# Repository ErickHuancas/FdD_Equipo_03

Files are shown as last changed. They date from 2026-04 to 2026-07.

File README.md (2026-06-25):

# Equipo 03 - Fundamentos de Diseño
### Carrera de Ingeniería Informática, Industrial  y Ambiental
**Universidad Peruana Cayetano Heredia**

---

## 🌍 Descripción del Equipo  
Somos el **Equipo 03** del curso **Fundamentos de Diseño 2026-1**, conformado por estudiantes de la carrera de Ingeniería Informática, Industrial y Ambiental.  
Nuestro objetivo es aplicar la metodología de diseño para generar soluciones innovadoras con impacto social, tecnológico y ambiental.  

---

## 📌 Descripción

El equipo 03 desarrollará FreshTomato, un dispositivo tecnológico inteligente que clasifica tomates según su frescura y tiempo de vida útil utilizando ESP32-S3-WROOM-CAM, machine learning.

El objetivo principal de este proyecto es reducir perdidas en mercados, contribuyendo al cumplimiento de los ODS 2 (Hambre Cero), 11 (Ciudades Sostenibles), 12 (Producción y Consumo Responsable) y 13 (Acción por el Clima).

---

## ⚠️ Problemática en el Perú

En la costa peruana, especialmente en las principales zonas productoras como Ica, Lima y La Libertad, la cadena postcosecha del tomate enfrenta diversas dificultades documentadas por la industria y la academia:

1. **Pérdidas por maduración acelerada y reducción de vida útil**
   
   El tomate es una fruta climatérica que continúa su proceso de maduración después de la cosecha. Las temperaturas elevadas durante el almacenamiento y               transporte aceleran este proceso, reduciendo drásticamente su vida útil.

2. **Deterioro por almacenamiento inadecuado y exposición a condiciones variables**

   La exposición del tomate a temperaturas inadecuadas y a la luz acelera su maduración y favorece el desarrollo de daños fisiológicos:
      - Temperaturas superiores a 25°C: Aumentan la tasa respiratoria y aceleran la pérdida de calidad, provocando ablandamiento rápido y mayor susceptibilidada            daños mecánicos .
      - Temperaturas bajas (menores a 10°C): Pueden causar daño por frío (chilling injury), manifestándose como manchas superficiales, maduración irregular y               pérdida de sabor .
      - Humedad relativa baja (<85%): Acelera la pérdida de agua, provocando arrugamiento y pérdida de peso .

4. **Falta de herramientas accesibles para la evaluación de calidad**

   Actualmente, la evaluación de la calidad postcosecha del tomate se realiza mediante métodos subjetivos (presión manual u observación del color externo) o          destructivos (corte del fruto para verificar su estado interno). Los dispositivos comerciales existentes tienen costos elevados, lo que dificulta su               implementación en contextos rurales o de pequeña escala.

6. **Impacto ambiental por residuos**

    El desperdicio de Tomates genera un impacto negativo en el medio ambiente:
      - Los residuos orgánicos producen gases contaminantes durante su descomposición.
      - Se incrementa la cantidad de residuos sólidos en los mercados.
      - Se contribuye al cambio climático debido a la emisión de gases de efecto invernadero.

---

## 🍅 FreshTomato – Detector de Madurez y Factores Ambientales
### 💡 Propuesta de solución

Este proyecto tiene como objetivo desarrollar un sistema inteligente que detecte la frescura del tomate. Para ello, se emplean sensores de gases, temperatura y humedad, junto con visión artificial e inteligencia artificial.

La solución propuesta evalúa el estado interno del tomate sin dañarla, mediante el análisis de gases emitidos y características visuales externas.

A diferencia de los métodos tradicionales basados en inspección manual, esta propuesta permite una clasificación objetiva del producto. Además, estima el tiempo de vida útil restante, proporcionando información clave para la toma de decisiones.

### ¿Qué hace el dispositivo?

| Paso | Función |
|---|---|
| 1 | Captura una imagen del tomate con ESP32-S3-WROOM-CAM |
| 2 | Mide gases de descomposición con sensor MQ-135 |
| 3 | Registra temperatura y humedad con DHT22 |
| 4 | Clasifica el tomate como **Buen estado** o **mal estado** (Machine Learning con Edge Impulse) |
| 5 | Estima los *días de vida útil restantes* (1-12 días según temperatura y gas) |
| 6 | Muestra el resultado en una pagina web local|
| 7 | Envía una alerta al usuario con el estado y recomendación |

### 🎯 Población objetivo

Supermercados

Nos interesa trabajar en los siguientes **Objetivos de Desarrollo Sostenible (ODS):**
  
## 🌾 ODS 2: Hambre Cero

Este ODS busca la eliminación del hambre y garantizar que todas las personas tengan acceso a alimentos suficientes y nutritivos.

Nuestro grupo promueve el acceso equitativo a una alimentación sana, nutritiva y suficiente durante todo el año.

En el Perú, la inseguridad alimentaria es uno de los principales desafíos. Más de la mitad de la población se encuentra en riesgo, especialmente los niños y niñas, quienes no logran acceder a una alimentación adecuada.

Según la FAO (Organización de las Naciones Unidas para la Alimentación y la Agricultura), en 2024 el 51,7% de la población se encuentra en situación de inseguridad alimentaria moderada, lo que equivale a aproximadamente 17,6 millones de personas. Este dato posiciona al Perú como uno de los países con mayor prevalencia de inseguridad alimentaria en América del Sur.

La inseguridad alimentaria impacta directamente en el desarrollo infantil. Según el INEI (Instituto Nacional de Estadística e Informática), el 43,1% de los niños de 6 a 35 meses en Perú sufre anemia, lo que afecta su desarrollo físico y cognitivo.

Frente a esta problemática, existen iniciativas como World Vision, que promueve dietas balanceadas, estrategias multisectoriales y políticas públicas para combatir la anemia.

A nivel tecnológico, destacan:
- Plantix, desarrollada por PEAT GmbH, que utiliza inteligencia artificial para detectar enfermedades en cultivos.
- Crop Analytica, que emplea sistemas IoT para monitorear cultivos en tiempo real.
- Infarm, que implementa agricultura urbana con sensores en granjas verticales, reduciendo el uso de agua hasta en un 90–95%.

## 🏙️ ODS 11: Ciudades y Comunidades Sostenibles

Según el World Air Quality Report 2022, Perú se encuentra entre los países con mayor contaminación del aire en Latinoamérica.

Uno de los factores contribuyentes es la emisión de gases de efecto invernadero generados por la pérdida de alimentos. Cerca de 12,8 millones de toneladas de alimentos se desperdician al año, de los cuales más del 50% termina en botaderos.

Esto provoca la liberación de metano, un gas altamente contaminante, y aumenta la incidencia de enfermedades respiratorias en las zonas cercanas.

El ODS 11 busca el desarrollo de ciudades sostenibles, inclusivas y seguras, donde se garantice una buena calidad de vida sin comprometer el medio ambiente.

Ejemplos de soluciones:
- En California, el Laboratorio Nacional Lawrence Berkeley desarrolló sistemas para capturar metano en rellenos sanitarios y transformarlo en energía.
- Estudiantes de la Universidad de Alicante crearon un biosensor que detecta la frescura de alimentos, reduciendo el desperdicio.

## ♻️ ODS 12: Producción y Consumo Responsable

Este ODS promueve un modelo de consumo y producción sostenible, fundamental para las generaciones presentes y futuras.

Nuestro grupo promueve abordar la tercera meta que involucra este ODS que es poder reducir a la mitad el desperdicio de alimentos de alimentos per cápita en zonas rurales del Perú.

En el Perú:
- Se desperdician 12.8 millones de toneladas de alimentos al año (47.6% del total).
- Cada persona desperdicia en promedio 67.34 kg de alimentos al año.

Mientras tanto, más de 17 millones de peruanos viven en situación de inseguridad alimentaria.

Como señaló el Banco de Alimentos del Perú, una mejor gestión permitiría alimentar a millones de personas.

Ejemplos de soluciones:
- Too Good To Go, aplicación que permite comprar alimentos no vendidos a menor precio.
- Sistemas IoT para detectar la descomposición temprana de alimentos.

## 🌍 ODS 13: Acción por el Clima

Según el Ministerio del Ambiente, el Perú solo genera alrededor del 0.4% de los gases de efecto invernadero a nivel mundial. Sin embargo, es considerado el tercer país más vulnerable frente al cambio climático. Esta vulnerabilidad se refleja en distintos desastres naturales que afectan directamente a la población. Entre los años 2008 y 2019, aproximadamente 656,000 personas se vieron obligadas a abandonar sus hogares, perdiendo no solo sus viviendas, sino también sus medios de sustento.

Frente a esta situación, el ODS 13 tiene como propósito principal tomar medidas urgentes para combatir el cambio climático y reducir sus impactos. Nuestro proyecto aborda específicamente la meta 13.1, que busca fortalecer la resiliencia y la capacidad de adaptación a los riesgos climáticos, contribuyendo a reducir el desperdicio de alimentos y, con ello, las emisiones de metano generadas por residuos orgánicos en vertederos.

Algunos ejemplos de proyectos que contribuyen a este objetivo son:

- El Copernicus Programme, impulsado por la Unión Europea, que utiliza satélites y sensores para observar la Tierra en tiempo real y proporcionar datos abiertos sobre el medio ambiente.

- En El Salvador, se desarrolló un sistema IoT de bajo costo que permite monitorear la calidad del aire y acceder a información sobre la contaminación desde cualquier dispositivo con conexión a internet.

---

## 📚 Fuentes

Alicante, N. U. de. (2024). NANOBIOPOL (Grupo de investigación de Análisis de Polímeros y Nanomateriales)

CH4 Pathways. (s/f). Captura del gas de rellenos sanitarios

Coca Pimentel, V. (2023, septiembre 23). Contaminación del aire en Perú: El 58% proviene del parque automotor.

Comex.Perú. (2022, febrero 11). Solo aprovechamos el 1% de residuos orgánicos e inorgánicos que generamos.

Dirección de Estudios Económicos & Dirección General de Políticas Agrarias. (2022). Pérdidas y desperdicios de alimentos en el Perú. 

MINAM. (2024, mayo 16). Más de 148 500 toneladas de residuos sólidos municipales son valorizados en el país.

Visión Mundial Perú. (2024, 10 de diciembre). Inseguridad alimentaria en Perú.

AgroPerú Informa. (2025, septiembre 23). Pérdida y desperdicio de alimentos: un reto que exige innovación y colaboración.

La República. (2021, marzo 20). En el Perú, la mitad de los alimentos termina en la basura, según estudio.

IoT M2M Council. (2021, marzo 17). Infarm launches new vertical farming centres. Hasib, A., & Sarkar Akib, A. S. M. A. (2026).

An IoT-based smart plant monitoring and irrigation system with real-time environmental sensing, automated alerts, and cloud analytics. arXiv.

---

## 📸 Fotografía del Equipo  
<p align="center">
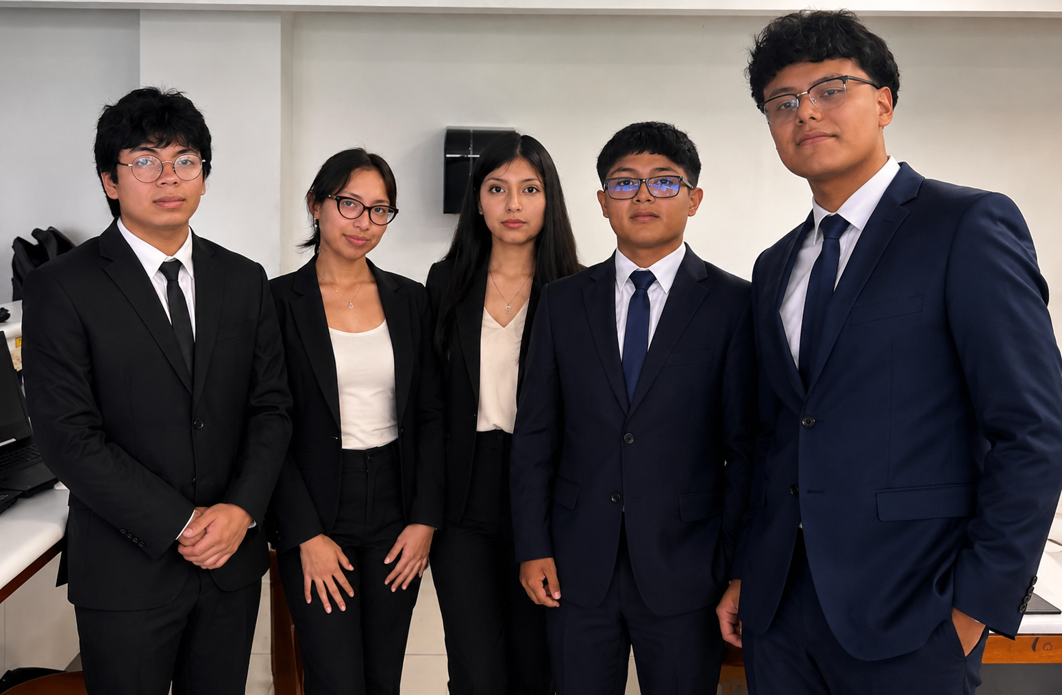
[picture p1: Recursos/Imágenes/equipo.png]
imagen_alumnos_IA

  <em>Figura 1. Fotografía del equipo 03</em>
</p>

---

## 👥 Integrantes del Equipo  

| Foto | Nombre | Rol | Intereses |
|---|---|-----|---|
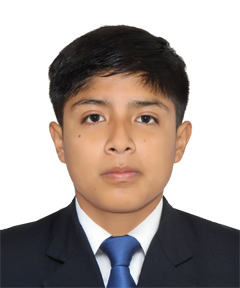
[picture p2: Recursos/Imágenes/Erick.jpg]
|  | **Erick Huancas Bereche** erick.huancas@upch.pe| Líder del equipo | Innovación social, sostenibilidad, liderazgo, emprendedor |
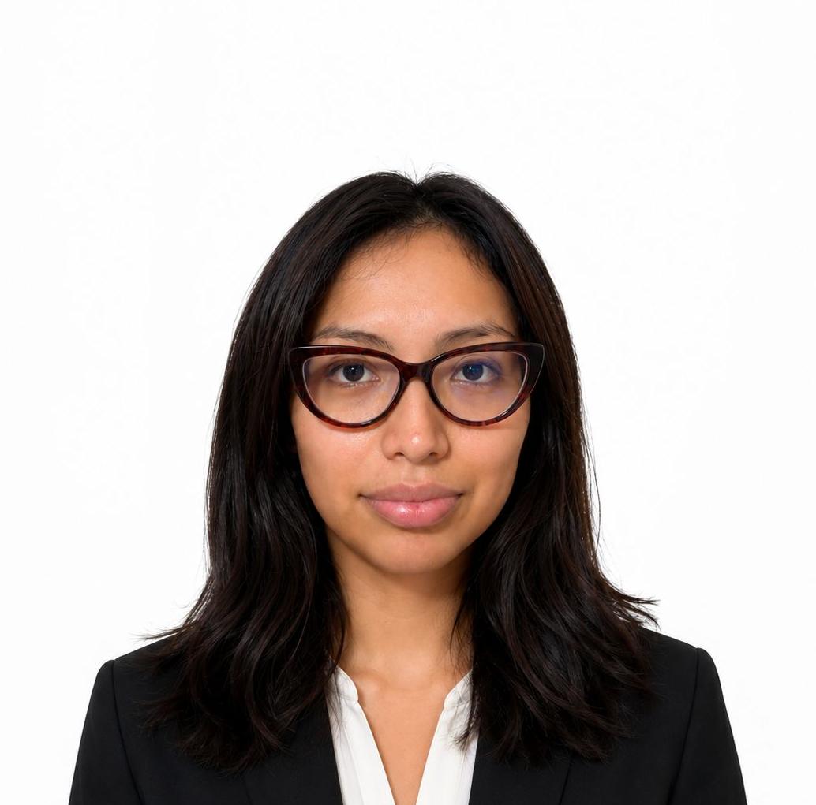
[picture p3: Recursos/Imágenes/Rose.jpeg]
|  | **Rose Suazo Davila** rose.suazo@upch.pe | Responsable de investigación | Gestión ambiental, desarrollo comunitario, investigación cientifica |
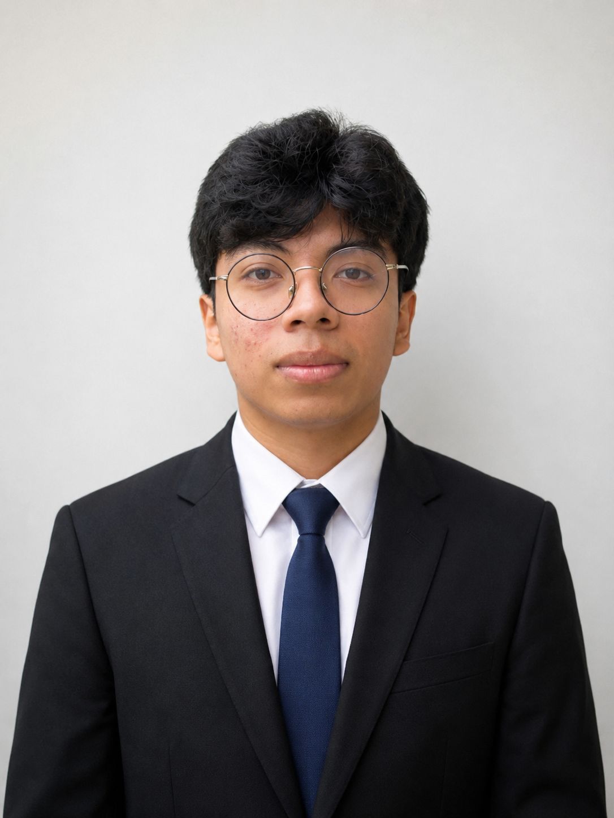
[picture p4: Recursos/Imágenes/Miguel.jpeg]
|  | **Miguel Ruiz Trelles** miguel.ruiz@upch.pe | Diseñador/a | Diseño de prototipos, creatividad aplicada, impacto ambiental |
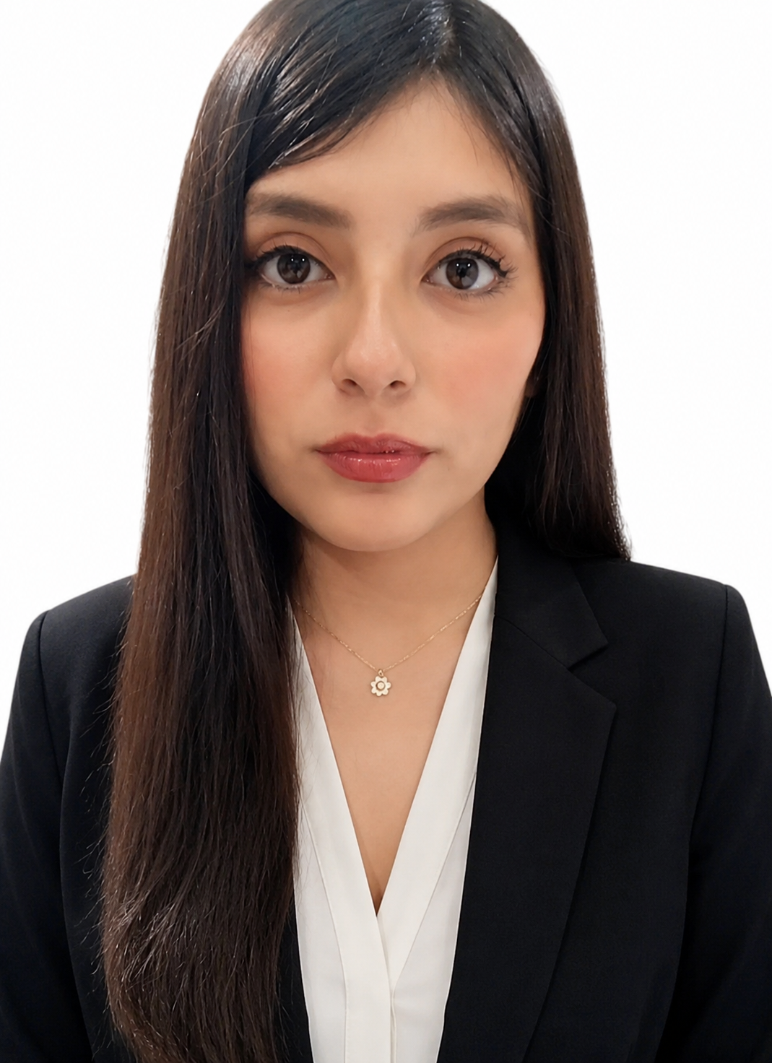
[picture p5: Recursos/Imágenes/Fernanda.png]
|  | **Paloma Velasquez Saforas** paloma.velasquez@upch.pe | Encargado/a de documentación | Comunicación científica, redacción técnica, investigación |
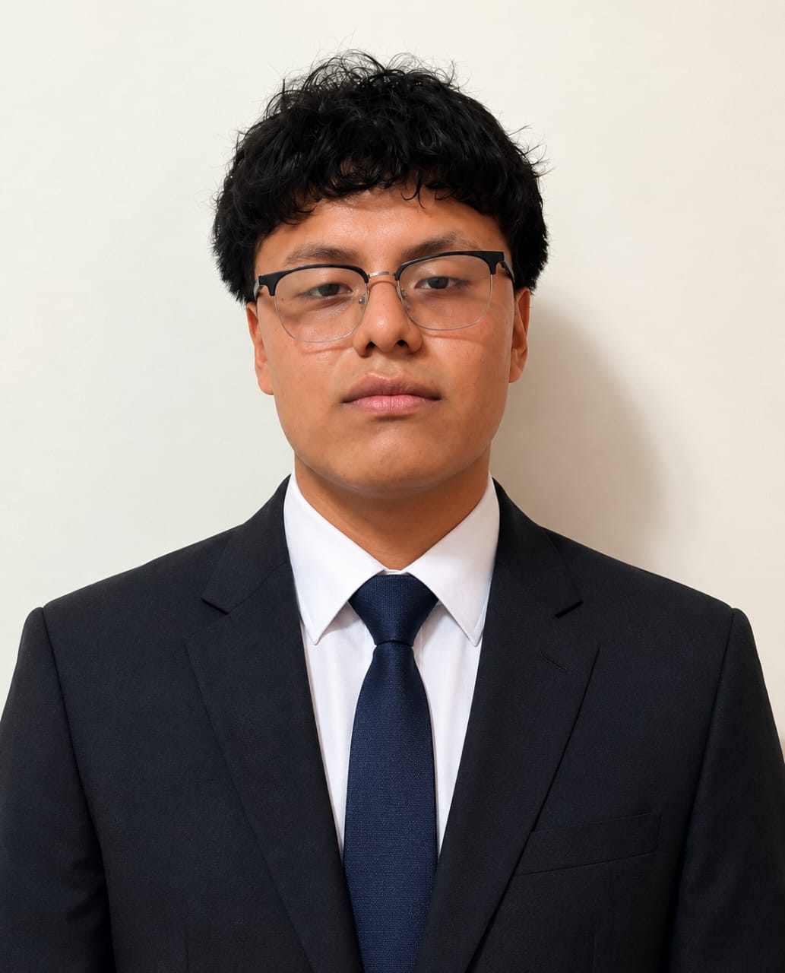
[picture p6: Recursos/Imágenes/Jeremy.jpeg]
|  | **Jeremy Mendez Ponce De Leon** jeremy.mendez@upch.pe | Programador/a - Modelador/a | Programación, análisis de datos, simulación |

---

## 📌 Resumen Final  
Este README resume quiénes somos, qué nos motiva y en qué ODS queremos enfocar nuestro trabajo durante el curso.

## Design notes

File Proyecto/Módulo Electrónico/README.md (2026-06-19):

# Reporte de Evolución y Mejoras del Diseño Esquemático
## Proyecto: Sistema de Monitoreo Agrícola "FreshTomato"

Este documento presenta de forma técnica y detallada la evolución del diseño electrónico del proyecto **FreshTomato**, detallando el histórico de las cuatro (4) versiones del esquemático hasta consolidar una solución final estable, eficiente y protegida contra ruidos eléctricos y conflictos de hardware.

---

## 📊 Cuadro Comparativo de Versiones

| Parámetro / Componente | Versión 1.0 (Inicial) | Versión 2.0 (Transición) | Versión 3.0 (Corrección) | Versión Final (Estabilizada) |
| :--- | :--- | :--- | :--- | :--- |
| **Microcontroladores** | 2 placas (ESP32 DevKit + ESP32-CAM) | 1 placa (ESP32-S3-WROOM-1 CAM) | 1 placa (ESP32-S3-WROOM-1 CAM) | 1 placa (ESP32-S3-WROOM-1 CAM) |
| **Actuador (Servo)** | No incluido | MG996R (Conectado a salida Stepdown) | MG996R (Conectado a salida Stepdown) | MG996R (Línea de 7.2V directa + Switch) |
| **Alimentación General** | Fuentes separadas no reguladas | Stepdown de 7V a 5V general | Stepdown de 7V a 5V general | **Fuentes Independientes (USB + Cargador 5V/2A + 7.2V)** |
| **Manejo de Pines (CAM)** | Sin restricciones (No integrados) | **Conflicto Crítico** (Pines de la cámara ocupados) | **Corregido** (Reasignación a pines libres) | **Optimizado** con protección en la señal del Servo |
| **Filtrado MQ135** | Sin capacitor de desacoplo | Sin capacitor de desacoplo | Sin capacitor de desacoplo | **Capacitor Electrolítico de 100 µF** |
| **Protección Lógica** | No incluida | No incluida | No incluida | **Divisores resistivos** para entradas analógicas/lógicas |

---

## 🔍 Análisis Detallado de la Evolución del Circuito

### 🔴 Versión 1.0: Arquitectura Duplicada (Inicial)
La primera aproximación del proyecto dependía de dos procesadores independientes para segmentar las tareas:
* **Componentes:** Un ESP32 clásico (para la lectura de sensores) y un ESP32-CAM (únicamente dedicado al procesamiento de imágenes).
* **Limitaciones:** El circuito no incluía servomotor. Carecía de filtros de desacoplo en la línea del sensor de gas MQ135, lo que provocaba lecturas altamente inestables debido al ruido térmico del calentador interno del sensor. La comunicación entre ambos microcontroladores complejizaba innecesariamente el código y aumentaba el consumo energético.

### 🟠 Versión 2.0: Unificación de Hardware y Errores de Conmutación
Con el fin de optimizar costos y espacio, se migró a un único procesador potente y se introdujo fuerza mecánica:
* **Mejoras:** Se reemplazaron las dos placas por un único **ESP32-S3-WROOM-1 CAM**. Se integró el servomotor de alto torque (MG996R) y un regulador conmutado *Stepdown* para reducir el voltaje de las baterías de 7V a 5V.
* **Errores Críticos Identificados:** 1.  **Conflicto de Pines CSI:** Se asignaron las líneas de control del servo (`GPIO6`), el DHT22 (`GPIO4`) y el MQ135 (`GPIO1`) a pines que la cámara utiliza internamente para el bus de datos y bus de control SCCB. Esto corruptora las capturas de imagen y reseteaba el procesador.
    2.  **Cortes de Tierra:** El interruptor general se ubicó interrumpiendo la línea de masa (`GND`), dejando el circuito flotante.

### 🟡 Versión 3.0: Corrección de Matriz de Pines
Esta versión se enfocó exclusivamente en resolver la interacción de hardware a nivel de software y distribución de pistas:
* **Mejoras:** Se realizó un mapeo profundo de la hoja de datos del ESP32-S3 CAM. Se liberaron por completo los pines internos de la cámara y se reubicaron las señales del Servo, DHT22 y MQ135 hacia GPIOs libres (como `GPIO8`, `GPIO9`, etc.). El interruptor fue movido a la línea positiva antes de la regulación.

### 🟢 Versión Final: Independencia de Potencia y Estabilidad Señal-Ruido
La versión definitiva del esquemático soluciona los problemas de caídas de tensión y picos de corriente aislando los caminos eléctricos por su naturaleza de consumo:

1.  **Aislamiento de la Etapa de Potencia del Servomotor:** * El servomotor MG996R demanda corrientes pico elevadas al romper la inercia. Se conectó de forma directa a la línea del portabaterías de **7.2V** (aprovechando su rango máximo de operación).
    * Se le integró un **Switch dedicado** en el positivo para cortar su energía cuando no esté operando, erradicando el consumo parásito y previniendo sobrecalentamientos.
2.  **Filtrado Eléctrico para el Sensor MQ135:**
    * El MQ135 posee una resistencia calefactora que genera picos cíclicos de demanda. Para mitigar las fluctuaciones en las lecturas analógicas, se energizó mediante un **cargador externo dedicado de 5V a 2 Amperios**.
    * Se colocó un **capacitor electrolítico de 100 µF** en paralelo entre `VCC` y `GND` del sensor, absorbiendo los rizos de corriente y estabilizando los voltajes de lectura.
3.  **Alimentación Lógica Limpia:**
    * El **ESP32-S3-WROOM-1 CAM** y el sensor **DHT22** se alimentan mediante el bus USB conectado a una laptop, garantizando una fuente conmutada limpia, ideal para el procesamiento de la IA y el envío de datos.
4.  **Adaptación de Niveles con Divisores Resistivos:**
    * Se incluyeron **divisores resistivos** calculados en las salidas de las señales analógicas/lógicas para adecuar los voltajes al rango seguro de tolerancia del ADC del ESP32-S3 ($0	ext{ V} - 3.3	ext{ V}$), protegiendo las compuertas lógicas contra degradación por sobrevoltaje.

---

## 🎯 Conclusión del Proceso de Ingeniería
El diseño final abandonó la regulación única con *Stepdown* general debido a que los tirones del servomotor y el ruido del calefactor del MQ135 degradaban la estabilidad del ESP32-S3. La arquitectura final de **Fuentes Distribuidas** (Batería 7.2V para motor + Cargador 5V/2A para sensor de gas + USB para lógica) asegura un funcionamiento continuo de 24/7 sin reinicios imprevistos, lecturas analógicas confiables y una captura de video nítida.

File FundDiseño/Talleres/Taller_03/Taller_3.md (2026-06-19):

# CAPÍTULO I: INTRODUCCIÓN

## Situación Problemática

---

## Contexto General
El desperdicio de alimentos es una problemática significativa y persistente en los sistemas alimentarios de hoy en día.  En el Perú, existen estudios sobre pérdidas en la agricultura que señalan niveles altos de desperdicio orgánico, especialmente durante la poscosecha; donde las frutas y verduras son las más afectadas por su rápida descomposición y vida útil corta.

Entre los productos más afectados destaca el tomate (Solanum lycopersicum L.), una de las hortalizas de mayor consumo en la dieta diaria peruana. Debido a su alta perecibilidad y elevado contenido de agua, este cultivo presenta una rápida pérdida de calidad durante las etapas de almacenamiento y comercialización, lo que genera importantes pérdidas antes de llegar al consumidor final. Diversos estudios sobre manejo poscosecha señalan que el deterioro del tomate está estrechamente relacionado con condiciones inadecuadas de manipulación, temperatura y tiempo de almacenamiento, factores que incrementan significativamente las pérdidas dentro de la cadena de comercialización (1,2)

A nivel nacional, los informes señalan a la podredumbre como causa principal con un 27% de las pérdidas. Por otro lado, el verdeamiento y la pérdida de agua con un 22% y 14% respectivamente. Asimismo, los golpes mecánicos y la mala clasificación de los tomates cada uno con un 11% de las pérdidas. Por lo tanto, la monitorización de las condiciones ambientales durante la distribución y venta es crítica para mitigar la degradación acelerada del tomate (2).

En este contexto, el desperdicio de tomate en los mercados representa una problemática persistente dentro de la cadena de abastecimiento alimentario, asociada principalmente a deficiencias en el manejo poscosecha, almacenamiento y comercialización, generando impactos económicos para comerciantes y productores, así como una mayor contribución en los niveles de desperdicios de alimentos generados. 

## Contexto en el sector comercial
En el sector retail, las pérdidas de los alimentos perecibles, como el tomate, tiene un impacto significativo en la cadena de suministro y durante la gestión de inventario; proceso que busca conservar la calidad del producto hasta la obtención final del cliente mediante un elevado nivel de gestión en el planeamiento de su logística. Por lo tanto, es necesario mencionar que la vida útil del tomate no está en función únicamente de factores biológicos, sino de las condiciones de almacenamiento en la que se encuentra al establecerse en las cadenas de retail alimentario (3). 

Este comercio minorista de alimentos cuenta con una amplia gama de estrategias para minimizar el desperdicio y evitar que sus productos caduquen antes de ser comprados. Sin embargo, muchos de los mecanismos empleados no permiten un mayor control sobre los alimentos. Dentro de las políticas de inventarios, a menudo se utilizan los sistemas de seguimiento de inventario First-In-First-Out (FIFO), que refiere a la venta de los productos que se adquieren primero, quedando en el inventario los productos que fueron adquiridos recientemente (4). No obstante, un estudio no experimental mediante encuestas en una de las grandes cadenas de retail, evidenció que el nivel de uso y efectividad del sistema FIFO es baja, esto confirma que la gestión de inventarios basada únicamente en un sistema dinámico de almacenaje es insuficiente para productos de alta tasa respiratoria como el tomate. (4) Este mecanismo ignora la variabilidad biológica de cada lote de tomate, es decir que la jaba adquirida recientemente presenta índices de emisión de etileno superiores a los de una jaba antigua.

 Por consiguiente, para apoyar de manera eficiente la cadena de suministro, no solo basta con el uso de una cadena de frío con condiciones de temperaturas óptimas, sino del uso de tecnologías que sean capaces de monitorear el estado fisiológico del tomate; logrando detectar anomalías químicas en lotes específicos que la temperatura no logra revelar y asegurando una toma de decisiones basada en el estado real de degradación del producto. 

---

# Propuesta de solución
En el Perú, especialmente en regiones costeras como Ica, Lima y La Libertad, los supermercados enfrentan pérdidas significativas de tomate debido a condiciones inadecuadas de almacenamiento y exhibición. Factores como temperaturas no controladas, variaciones de humedad y largos tiempos de exposición aceleran el deterioro del producto, reduciendo su vida útil en los puntos de venta. Asimismo, la evaluación de la calidad del tomate se realiza principalmente mediante inspecciones visuales, las cuales son subjetivas y dependen del criterio del personal, lo que limita la detección temprana del deterioro; además, muchos establecimientos no cuentan con sistemas tecnológicos que permitan un monitoreo continuo, objetivo y en tiempo real.

Según un estudio, demostró que la calidad del tomate, evaluada mediante atributos como firmeza, color e índice general de calidad, disminuye rápidamente bajo condiciones ambientales, afectando directamente su aceptación por parte del consumidor. En particular, se ha evidenciado que solo una pequeña proporción de tomates en estado deteriorado mantiene aceptación comercial, lo que resalta la necesidad de implementar sistemas de monitoreo temprano y preciso que permitan evitar pérdidas y rechazos en el punto de venta.(5)

Enfrentados a este problema, es necesario encontrar soluciones tecnológicas que nos permitan monitorear la situación de manera objetiva. Para resolver esto, se propone crear un sistema inteligente llamado FreshTomate. Este sistema utiliza sensores que miden los gases, la temperatura y la humedad, además de técnicas de visión artificial y de inteligencia artificial. Todo esto nos permite monitorear el estado del tomate en tiempo real.

El sistema se aplicará en un momento crítico de la cadena de suministro, específicamente durante la etapa de recepción de mercancía, es decir, antes de que los tomates entren a la cadena de frío. En este lugar, el aparato operará como un filtro de calidad, posibilitando la revisión del estado del producto previo a su almacenamiento en cámaras frigoríficas. Así, se previene que entren productos en malas condiciones que pudieran perjudicar la calidad del lote restante.
Para su funcionamiento, el sistema utiliza un microcontrolador llamado ESP32-CAM. Este microcontrolador permite procesar datos y capturar imágenes del tomate para analizarlo.(6,7) También se utiliza un sensor de gases llamado MQ-135. Este sensor detecta gases como amoníaco y dióxido de carbono que se producen cuando el tomate se descompone.(8) Además, se utiliza un sensor llamado DHT22 para medir la temperatura y la humedad. Estas variables son importantes porque influyen en la maduración del tomate.(9)

Los datos que se recopilan de estos sensores se procesan con una herramienta de aprendizaje automático desarrollada con Edge Impulse. Esta herramienta puede ser entrenada para clasificar el estado del tomate en dos categorías: apto para el consumo y no apto para el consumo. Esta clasificación es rápida y no daña el tomate. Es mejor que los métodos tradicionales.

Además, el sistema dispondrá de una fuente de alimentación con baterías, lo que posibilitará su funcionamiento independiente y hará más fácil su instalación en varios lugares dentro del área de recepción sin la necesidad de tener una conexión eléctrica fija.

En resumen, el sistema permite vigilar las condiciones ambientales y el estado del tomate. Esto nos da alertas antes de que haya problemas y nos ayuda a tomar decisiones. Con tecnologías modernas y fáciles de usar, podemos mejorar la calidad, reducir el desperdicio de comida y gestionar mejor los supermercados. Además, esto se ajusta a la norma ISO 22000, que busca asegurar que los alimentos sean seguros y controlar los riesgos en toda la cadena de suministro del tomate.

---

# Objetivos

## Objetivo general

Diseñar e implementar un sistema ciberfísico inteligente denominado FreshTomate, basado en el uso del microcontrolador ESP32-CAM, sensores ambientales y técnicas de aprendizaje automático, que permita evaluar y monitorear en tiempo real la vida útil del tomate (Solanum lycopersicum L.)

## Objetivos específicos

- Realizar un estudio del estado del arte que permita identificar las tecnologías aplicadas en la detección de la frescura de alimentos, incluyendo sensores de gases, visión artificial e inteligencia artificial.
- Desarrollar el sistema físico mediante la selección e integración de componentes electrónicos, incluyendo sensores de gas, temperatura y humedad, así como el módulo ESP32-CAM para la captura de imágenes.
- Diseñar e implementar un modelo de inteligencia artificial que permita clasificar la frescura del tomate y estimar su vida útil, utilizando técnicas de aprendizaje automático.
- Realizar pruebas de funcionamiento para validar la precisión en la detección de la frescura y el procesamiento de datos provenientes de los sensores y del sistema de visión artificial.
- Evaluar el desempeño del sistema mediante pruebas experimentales, comparando los resultados obtenidos con métodos tradicionales de inspección manual en la detección temprana del deterioro del tomate, en condiciones similares al entorno comercial.

---

# CAPÍTULO II: ESTADO DE ARTE
## Métodos tecnológicos para la detección de frescura y descomposición en frutas y vegetales
De acuerdo con la literatura revisada (10,11), existen diferentes métodos tecnológicos para el monitoreo y detección de frescura en alimentos, que mediante el uso de microcontroladores, sensores de gas y algoritmos de inteligencia artificial (Edge Impulse) permiten clasificar el estado de maduración o descomposición de frutas y vegetales. 

Asimismo, investigaciones recientes evidencian el uso de tecnologías IoT con dispositivos como ESP32, combinados con sensores y plataformas en la nube, para el monitoreo en tiempo real de la calidad de los alimentos durante su almacenamiento y transporte (11).

Además de los artículos académicos revisados, existen implementaciones prácticas documentadas en plataformas de código abierto. Markel (2025) desarrolló un sistema de detección de madurez aplicable a frutas utilizando Machine Learning, logrando una precisión del 100% en sus pruebas con tomates, demostrando la viabilidad técnica del enfoque.

---

## Clasificación de tomates con ESP32-CAM y Edge Impulse

Consiste en el uso de un microcontrolador ESP32-CAM con cámara integrada (OV2640, 2 megapíxeles) que captura imágenes de tomates en tiempo real. Estas imágenes son procesadas mediante un modelo de red neuronal convolucional profunda ResNet entrenado en la plataforma Edge Impulse. El sistema clasifica los tomates en diferentes categorías según su tamaño, madurez y calidad. Los datos se transmiten a una plataforma IoT en la nube, permitiendo a los agricultores acceder a la información de forma remota para tomar decisiones sobre la cosecha y reducción de desperdicios.(10)

Entre sus principales ventajas destaca el uso de hardware de bajo costo, como el ESP32-CAM, así como el empleo de la plataforma Edge Impulse, que es gratuita. Además, el sistema presenta un gran potencial para reducir el desperdicio de alimentos a lo largo de la cadena de suministro.(10)

Sin embargo, también presenta algunas limitaciones. Una de ellas es la limitada integración de sensores, ya que los propios autores señalan que, como trabajo futuro, será necesario incorporar sensores ambientales adicionales (como temperatura, humedad y gases). Asimismo, el sistema depende de la conexión a internet, por lo que, ante una falla en la conectividad, deja de funcionar correctamente.(10)

## Desarrollo de una plataforma basada en IoT y aprendizaje automático para la evaluación de la madurez de la fruta y la detección de su deterioro.

Se trata de la creación de un sistema que utiliza Internet de las Cosas (IoT) y aprendizaje automático con el fin de analizar la maduración y encontrar frutas en mal estado, haciendo uso para ello de un microcontrolador ESP32. El sistema cuenta con sensores como el SHT40 para determinar la humedad y la temperatura, y el SGP30 para identificar gases como compuestos orgánicos volátiles (TVOC), CO₂ equivalente, hidrógeno y etanol. Estos son indicadores fundamentales del proceso de descomposición y maduración. Los datos se recopilan en tiempo real y se transfieren a la plataforma ThingSpeak, que está basada en la nube. En esta plataforma, los datos son almacenados, procesados y visualizados para crear un conjunto de datos que facilita el entrenamiento de modelos de machine learning con el objetivo de prever el estado de la fruta desde su fase inicial hasta su deterioro.(11)

Entre sus principales ventajas destaca la integración de sensores avanzados que pueden medir tanto las variables ambientales como los gases específicos relacionados con el proceso de maduración es uno de sus principales beneficios, lo cual facilita un análisis más exacto e imparcial. Además, el empleo del ESP32 hace posible la transmisión de datos sin cables y el seguimiento remoto en tiempo real a través de plataformas IoT como ThingSpeak. Asimismo, la creación de conjuntos de datos a través del tiempo mejora la exactitud de los modelos predictivos y favorece el avance de sistemas inteligentes utilizados en agricultura y conservación alimentaria.(11)

Sin embargo, el sistema también presenta algunas limitaciones. Una de ellas es la necesidad de recolectar grandes volúmenes de datos durante varios días para lograr modelos de aprendizaje automático confiables. Asimismo, el rendimiento de los sensores de gases puede verse afectado por condiciones ambientales externas y por su propia degradación con el tiempo, lo que exige calibraciones y mantenimiento periódico. También existe la posibilidad de obtener mediciones alteradas debido a interferencias del entorno, lo que podría generar errores en la clasificación. Por otro lado, su implementación requiere cierto nivel de conocimiento técnico y una inversión inicial. Finalmente, el sistema depende de la conectividad a internet para el envío y visualización de datos en la nube, lo que puede representar una limitación en entornos con baja cobertura.(11)

## BIBLIOGRAFÍA
- Córdova Peña, Moisés Teodoro, Pinasco Alegre, Renzo Giovanni, Pizarro Chirinos, Giannina Josefina, Quiñones Jara, Teófilo Marcelo, Córdova Peña. laneamiento Estratégico del Tomate en el Perú [Tesis de maestría]. [Surco, Perú]: Pontificia Universidad Católica del Perú; 2016. 
- María Yovani Irigoín Lara. Vida útil de tomate (Solanum lycopersicum L. var. Sheila Victory F1) cosechado en dos estados de madurez y almacenados en diferentes tiempos y temperaturas [Tesis para optar el título profesional de Ingeniero en Industrias Alimentarias]. [Cajamarca, Perú]: Universidad Nacional de Cajamarca; 2024. 
- Salas BDM, David O, Díaz P, Joel D, Lozano V, Vanessa C. GESTIÓN DE   INVENTARIOS PERECIBLES ADAPTADA PARA LAS DECISIONES SOBRE EL SUMINISTRO: ESTUDIO DE CASO DEL PROCESO DE PLANIFICACIÓN DEL ABASTECIMIENTO DE YOGURES EN HIPERMERCADOS TOTTUS.
- Espinoza DRL. Gestión de Inventarios y la merma de productos perecederos en hipermercados Tottus. 2023;115.
- M R, Voola P. Developing an IoT and ML-driven platform for fruit ripeness evaluation and spoilage detection: A case study on bananas. E-Prime - Adv Electr Eng Electron Energy. el 1 de marzo de 2025;11:100896. doi:10.1016/j.prime.2025.100896
- Aftab RA, Ahmad F, Monish M, Zaidi S. Postharvest quality assessment of tomato during storage: An experimental and ML fusion. J Stored Prod Res. 1 de mayo de 2025;112:102643. doi:10.1016/j.jspr.2025.102643
- Kulkarni SM, Umadi S, R m A, Airani SS, Raikar MM. Grading and Classification of Tomatoes Using ESP32-CAM and Impulse Cloud based IoT Platform for Sustainability. Procedia Comput Sci. 1 de enero de 2025;Seventh International Conference on Recent Trends in Image Processing and Pattern Recognition (RTIP2R-2024)260:938-46. doi:10.1016/j.procs.2025.03.277 
- Santos S. Guía de asignación de pines del ESP32-CAM AI-Thinker: Explicación del uso de los GPIO | Tutoriales de Random Nerd [Internet]. 10 de marzo de 2020 [citado 2 de abril de 2026]. Disponible en: https://randomnerdtutorials.com/esp32-cam-ai-thinker-pinout/
- Tangirbergen A, Tleubekova A, Yergaliuly G, Kurmanbayeva A, Soltabayev B, Soltabayeva A. Real-time detection of potato spoilage by gas sensor array coupled with microbiological analysis. LWT. 1 de enero de 2026;239:118926. doi:10.1016/j.lwt.2025.118926
- K.VENKATARAMANAN, D.PRASANTH, V.SHEEBA, R.KUMARESAN. SMART FOOD SPOILAGE PREDICTION AND ALERT SYSTEM. Int J Nexus Knowl Multidiscip J Online ISSN 3108-0529. 3 de julio de 2025;1(1):62-9.
- M R, Voola P. Developing an IoT and ML-driven platform for fruit ripeness evaluation and spoilage detection: A case study on bananas. E-Prime - Adv Electr Eng Electron Energy. 1 de marzo de 2025;11:100896. doi:10.1016/j.prime.2025.100896

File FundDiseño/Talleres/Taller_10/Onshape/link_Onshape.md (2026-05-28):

https://cad.onshape.com/documents/e68281a320b0caf378c65360/w/9e2ba7427c716612348f81b5/e/db65db4494cec690573642d6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

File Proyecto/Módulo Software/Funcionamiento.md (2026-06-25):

# Módulo de Software

## Descripción General

El módulo de software constituye el núcleo del sistema, permitiendo la comunicación entre el sistema embebido ESP32-S3-WROOM-CAM, el servidor Flask, el modelo de Machine Learning y la interfaz de usuario. Su función principal es procesar las imágenes y datos ambientales adquiridos, estimar la vida útil del tomate y almacenar los resultados obtenidos.

---

# Componentes del Sistema

## Dashboard Web

La interfaz web permite:

- Iniciar una nueva evaluación.
- Visualizar el progreso del proceso.
- Mostrar los resultados de clasificación.
- Consultar el historial de análisis almacenados.

---

## Servidor Flask

El servidor Flask actúa como núcleo del sistema y es responsable de:

- Recibir las solicitudes provenientes del Dashboard.
- Comunicarse con el ESP32-S3-WROOM-CAM mediante HTTP.
- Procesar las imágenes capturadas.
- Ejecutar el modelo de Machine Learning.
- Calcular la vida útil del tomate.
- Almacenar los resultados en una base de datos SQLite.

---

## Sistema Embebido ESP32-CAM

El ESP32-S3-WROOM-CAM se encarga de:

1. Consultar continuamente el estado del servidor.
2. Ejecutar un ciclo de adquisición cuando recibe una orden de inicio.
3. Posicionar el servomotor en tres ángulos diferentes (0°, 90° y 180°).
4. Leer la temperatura mediante el sensor DHT22.
5. Leer la concentración de gases mediante el sensor MQ135.
6. Capturar una imagen de cada cara del tomate.
7. Enviar la información al servidor Flask.

---

## Modelo de Machine Learning

Se emplea una red neuronal convolucional basada en MobileNetV2 entrenada para clasificar tomates en dos categorías:

- Tomate sano.
- Tomate malogrado.

El modelo recibe imágenes RGB de tamaño 224×224 píxeles y genera una probabilidad mediante una función de activación sigmoide.

La clasificación se realiza mediante:

- Probabilidad ≥ 0.5 → Tomate sano.
- Probabilidad < 0.5 → Tomate malogrado.

---

## Estimación de Vida Útil

La vida útil restante se estima considerando tres factores principales:

### Temperatura

Se emplea el modelo Q10, donde un incremento de 10°C aproximadamente duplica la velocidad de deterioro.

### Concentración de gases

El sensor MQ135 proporciona una medida relativa del deterioro mediante la detección de compuestos volátiles emitidos durante el proceso de maduración y descomposición.

### Confianza del modelo

La confianza obtenida por MobileNetV2 permite ajustar la estimación de forma conservadora cuando existen predicciones poco seguras.

---

# Flujo General de Funcionamiento

1. El usuario presiona el botón **"Iniciar Evaluación"** desde el Dashboard.
2. El Dashboard envía una solicitud POST al servidor Flask.
3. Flask genera un identificador único de sesión para asociar las tres caras del tomate.
4. El ESP32-S3-WROOM-CAM consulta periódicamente el estado del servidor mediante GET `/estado`.
5. Al recibir la orden de inicio, comienza el ciclo de adquisición.
6. El servomotor posiciona el tomate en tres orientaciones diferentes (0°, 90° y 180°).
7. En cada posición se registran:

   - Temperatura (DHT22).
   - Concentración de gases (MQ135).
   - Imagen capturada por la cámara.

8. Cada etapa es enviada al servidor Flask mediante HTTP POST.
9. Al completar las tres etapas, el ESP32-S3-WROOM-CAM notifica la finalización del proceso.
10. Flask procesa las imágenes utilizando MobileNetV2.
11. Se calcula la temperatura promedio y la concentración promedio de gases.
12. Se estima la vida útil restante del tomate.
13. Los resultados se almacenan en SQLite.
14. El Dashboard muestra la clasificación y el historial de evaluaciones.

---

# Comunicación Entre Componentes

## Dashboard → Flask

```text
POST /iniciar
```

Solicita el inicio de una nueva evaluación.

---

## ESP32 → Flask

Consulta periódicamente:

```text
GET /estado
```

para verificar si debe iniciar una nueva adquisición.

---

## Envío de las Etapas

Para cada etapa, el ESP32-S3-WROOM-CAM envía:

### Cabeceras HTTP

```text
X-Session
X-Etapa
X-Temp
X-MQ135
```

### Cuerpo del mensaje (Body)

```text
Imagen JPEG capturada por la ESP32-S3-WROOM-CAM
```

mediante:

```text
POST /etapa
```

---

## Finalización del Proceso

Una vez completadas las tres etapas:

```text
POST /finalizar
```

El servidor Flask procesa toda la información adquirida.

---

# Base de Datos SQLite

La información almacenada incluye:

- Fecha y hora del análisis.
- Identificador de sesión.
- Resultado de clasificación.
- Nivel de confianza.
- Temperatura promedio.
- Concentración promedio de gases.
- Vida útil estimada.
- Rutas de almacenamiento de las imágenes.

---

# Tecnologías Utilizadas

| Componente | Tecnología |
|---|---|
| Sistema Embebido | ESP32-S3-WROOM-CAM |
| Servidor | Flask |
| Lenguaje | Python |
| Machine Learning | TensorFlow + MobileNetV2 |
| Procesamiento de Imágenes | Pillow + NumPy |
| Base de Datos | SQLite |
| Comunicación | HTTP |
| Interfaz Gráfica | HTML + CSS + JavaScript |
| Sensor de Temperatura | DHT22 |
| Sensor de Gases | MQ135 |
| Actuador | Servo MG996R |

---

# Conclusión

El módulo de software integra la adquisición de datos, el procesamiento mediante inteligencia artificial, la estimación de vida útil y el almacenamiento de información, permitiendo la clasificación automática del estado del tomate y proporcionando una aproximación de su tiempo de conservación restante.

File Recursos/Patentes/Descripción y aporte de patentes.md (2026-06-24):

# Cuadros Técnicos de las Patentes del Proyecto

Este documento presenta los cuadros técnicos de las patentes identificadas para el proyecto.

---

## Cuadro Técnico de la Patente 01

| Componente | Detalle |
| :--- | :--- |
| **Título** | Método y dispositivo para detectar la madurez de frutas y verduras |
| **Título Original** | Method and device for detecting maturity of fruits and vegetables |
| **Código** | `CN114659918A` |
| **Enlace de consulta** | [Espacenet - CN114659918A](https://worldwide.espacenet.com/patent/search/family/082037969/publication/CN114659918A?q=detect%20maturity) |
| **Descripción / Resumen** | Este dispositivo permite detectar la madurez de frutas y verduras y está compuesto por una base que integra un detector en la parte superior derecha y una caja fija en la parte superior izquierda. Dentro de esta caja se ubican lámparas de iluminación en la parte frontal y posterior, así como una cubierta articulada que incorpora un sensor de color. Además, en su interior se encuentra un sensor de grado de azúcar. Para su funcionamiento, utiliza el sensor de color, el sensor de grado de azúcar y un medidor de dureza para registrar las características de madurez, las cuales son procesadas mediante un procesador y un módulo de comparación, apoyados por un módulo de selección y un módulo de análisis de madurez. Finalmente, el controlador de visualización muestra los resultados de la detección junto con el grado de madurez, lo que facilita su evaluación y mejora la precisión en comparación con equipos convencionales. |
| **Aporte** | El aporte principal de la presente patente radica en su modelo de procesamiento de datos, donde un procesador centraliza las lecturas de los sensores para posteriormente analizarlas a través del módulo de madurez con Machine Learning. Este flujo robustece el marco lógico del proyecto, proveyendo una base analítica sólida para entrenar y refinar los algoritmos de Machine Learning encargados de predecir con precisión la vida útil del tomate en entornos comerciales. |

---

## Cuadro Técnico de la Patente 02

| Componente | Detalle |
| :--- | :--- |
| **Título** | Dispositivo para el reconocimiento de un alimento y para la determinación de su grado de frescura |
| **Título Original** | Device for the recognition of a food and for the determination of the degree of freshness thereof |
| **Código** | `WO2024201242A1` |
| **Enlace de consulta** | [Google Patents - WO2024201242A1](https://patents.google.com/patent/WO2024201242A1/en) |
| **Descripción / Resumen** | Este dispositivo está diseñado para el reconocimiento de un alimento y la determinación de su grado de frescura, y está configurado para insertarse al menos parcialmente dentro de un recipiente que contiene dicho alimento. Comprende una carcasa externa con una cavidad interna que se comunica con el exterior mediante una abertura, la cual puede cerrarse herméticamente mediante un elemento de cierre. En el interior de la cavidad se dispone al menos un detector de gases, configurado para generar una señal indicativa de la concentración de gases. El dispositivo incluye además una unidad de procesamiento y control en comunicación con el detector de gases, capaz de generar, a partir de dicha señal, información sobre el tipo de alimento presente en el recipiente y su grado de frescura. Para su funcionamiento, puede operar en una configuración de ajuste o calibración, en la que la cavidad permanece aislada del entorno externo, y en una configuración de detección, en la que la cavidad se encuentra en comunicación con el interior del recipiente, permitiendo analizar los gases presentes. |
| **Aporte** | Esta patente aporta al proyecto al introducir el uso de sensores de gases como una alternativa no destructiva para evaluar la frescura de los alimentos. Además, proporciona una referencia sobre la integración de sistemas de detección y procesamiento capaces de analizar los gases emitidos durante el deterioro del producto, permitiendo determinar su estado de conservación. Estos conceptos constituyen una base importante para el desarrollo de tecnologías automatizadas orientadas al monitoreo y control de la calidad de productos agrícolas. |

---

## Cuadro Técnico de la Patente 03

| Componente | Detalle |
| :--- | :--- |
| **Título** | Sensor de Frescura del producto |
| **Título Original** | Produce freshness sensor |
| **Código** | `US11408820B` |
| **Enlace de consulta** | [Google Patents - US11408820B1](https://patents.google.com/patent/US11408820B1/en) |
| **Descripción / Resumen** | Este dispositivo consiste en un sensor de frescura para productos agrícolas, diseñado para ser de bajo costo y desechable, lo que permite su uso a lo largo del sistema de distribución. El sensor es fijado directamente al producto por el productor y monitorea parámetros que afectan su frescura, como el color y la composición química. Está compuesto por uno o más emisores, un sensor de temperatura, un microprocesador y un transceptor, todos montados en una placa de circuito impreso, permitiendo el monitoreo continuo del producto durante su recorrido. Asimismo, se establece una línea base inicial al momento de fijar el sensor, registrándose el tiempo de inicio y las mediciones iniciales; posteriormente, la información en tiempo real es procesada para proporcionar análisis y datos relevantes. |
| **Aporte** | Esta patente aporta al proyecto al introducir un sistema de monitoreo continuo de la frescura de productos agrícolas mediante sensores integrados de temperatura, emisores ópticos, microprocesadores y comunicación inalámbrica. Además, proporciona una referencia sobre la obtención de mediciones en tiempo real y el establecimiento de una línea base inicial para comparar los cambios que experimenta el producto durante su almacenamiento y distribución. Estos conceptos permiten comprender cómo variables como la temperatura, el color y la composición del alimento pueden utilizarse para determinar su estado de madurez y conservación, constituyendo una base importante para el desarrollo de tecnologías inteligentes orientadas al control de calidad y estimación de la vida útil de productos agrícolas. |

---

## Cuadro Técnico de la Patente 04

| Componente | Detalle |
| :--- | :--- |
| **Título** | Dispositivo de calibración para sensor de dióxido de carbono |
| **Título Original** | Calibration Device for Carbon Dioxide Sensor |
| **Código** | `US7174766B2` |
| **Enlace de consulta** | [Google Patents - US7174766B2](https://patents.google.com/patent/US7174766B2/e) |
| **Descripción / Resumen** | La patente describe un sensor de dióxido de carbono (CO2) autocalibrable diseñado para solucionar la pérdida de sensibilidad y el desfase que sufren estos equipos a lo largo de su vida útil debido a contaminantes ambientales. El dispositivo integra, dentro de una misma carcasa, un detector de CO2 (que puede ser electroquímico o infrarrojo) y un generador interno de gas de referencia. Este generador consta de un elemento calefactor en contacto térmico con un material sólido capaz de liberar gas (típicamente un carbonato del Grupo 2, como carbonato de magnesio o de calcio). Cuando el procesador del sistema activa el calentador a una temperatura y tiempo predeterminados, el sólido se descompone térmicamente liberando una cantidad exacta y conocida de CO2 de referencia. El detector mide este gas liberado y, si detecta desviaciones frente al valor teórico, el procesador ajusta automáticamente los parámetros de calibración del sensor sin necesidad de mantenimiento externo o inyección manual de gases. |
| **Aporte** | Esta patente aporta al proyecto al presentar un sistema de monitoreo continuo de la frescura de productos agrícolas mediante la integración de sensores, emisores ópticos, un microprocesador y comunicación inalámbrica. Además, introduce el uso de una línea base inicial para registrar las condiciones del producto y comparar los cambios que experimenta durante su almacenamiento y distribución. Estos conceptos permiten realizar un seguimiento en tiempo real de parámetros relacionados con la calidad del alimento, proporcionando una base para el desarrollo de sistemas inteligentes orientados a la evaluación del estado de conservación y la estimación de la vida útil de productos agrícolas. |

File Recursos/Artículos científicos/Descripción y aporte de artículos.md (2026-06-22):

# Cuadro Técnico de Artículos Científicos

## Artículo 01

| Campo | Detalle |
| :--- | :--- |
| **Título** | Evaluación de la calidad poscosecha del tomate durante el almacenamiento: una fusión experimental y de aprendizaje automático. |
| **Título Original** | Postharvest quality assessment of tomato during storage: An experimental and ML fusion |
| **DOI** | https://doi.org/10.1016/j.jspr.2025.102643 |
| **Enlace de consulta** | https://www.sciencedirect.com/science/article/pii/S0022474X2500102X |
| **Descripción/Resumen** | Este estudio evalúa los cambios físicos y químicos de tomates almacenados en condiciones ambientales durante 24 días, registrando aumentos en el pH y la relación azúcar-ácido, y reducciones en la firmeza, la acidez y el contenido de ácido ascórbico. A partir de los atributos químicos y pruebas de aceptación sensorial, los autores desarrollaron y validaron once modelos matemáticos para determinar el Índice de Calidad General (OQI) del fruto. El modelo denominado M3 demostró ser el más preciso y consistente con la evaluación de los panelistas, indicando que el tiempo óptimo de almacenamiento a temperatura ambiente de los tomates es de 12 días, momento en el cual el 33% de los consumidores aún mantiene una opinión favorable. Por otro lado, el descarte total del producto (100% de rechazo) ocurrió hacia el final del periodo, cuando el índice descendió a 0.004. Adicionalmente, la investigación integró herramientas de aprendizaje automático (redes neuronales artificiales y regresión de vectores de soporte) para predecir de manera no destructiva el OQI de seis variedades distintas de tomate. Estos modelos predictivos de machine learning demostraron una alta precisión (con un coeficiente de determinación R^2 > 0.99), consolidándose como alternativas eficientes para optimizar los procesos de almacenamiento, estimar la vida útil y reducir significativamente las pérdidas poscosecha en la industria agrícola. |
| **Aporte** | Para resolver las limitaciones de la inspección visual en la postcosecha, el estudio señalado aporta el fundamento científico y metodológico necesario para optimizar el almacenamiento del tomate mediante tecnologías predictivas. En este sentido, para cuantificar el deterioro de forma objetiva, los autores desarrollaron un Índice de Calidad General (OQI). Ante este escenario, el artículo valida con éxito el uso de Machine Learning mediante Redes Neuronales Artificiales (ANN) y Regresión de Vectores de Soporte (SVR) para predecir el estado del fruto. De este modo, el estudio sirve como sustento teórico directo para este proyecto, justificando rigurosamente que la integración de algoritmos de aprendizaje automático con sensores de temperatura, humedad y dióxido de carbono permite transformar el monitoreo pasivo en un sistema predictivo capaz de anticipar la madurez, estimar la vida útil real y prevenir pérdidas económicas en el punto de venta. |

## Artículo 02

| Campo | Detalle |
| :--- | :--- |
| **Título** | Detección en tiempo real del deterioro de la patata mediante una matriz de sensores de gas acoplada a un sistema microbiológico. |
| **Título Original** | Real-time detection of potato spoilage by gas sensor array coupled with microbiological |
| **DOI** | 10.1016/j.lwt.2025.118926 |
| **Enlace de consulta** | https://www.sciencedirect.com/science/article/pii/S0023643825016111 |
| **Descripción/Resumen** | Este estudio describe el desarrollo de un sistema de nariz electrónica (E-nose) de bajo costo, basado en una placa Arduino y una matriz de seis sensores de gases de óxido metálico (MOS), diseñado para la detección no invasiva y en tiempo real del deterioro en papas almacenadas. Los investigadores validaron el comportamiento de los sensores cruzando sus lecturas de resistencia eléctrica con análisis microbiológicos tradicionales (recuento de E. coli, coliformes, bacterias aeróbicas totales, mohos y levaduras) bajo tres entornos de almacenamiento distintos: ambiental, alta humedad y pre tratamiento con radiación UV. Los resultados demostraron una correlación directa entre la caída de resistencia en los sensores y el incremento de la carga microbiana debido a la liberación temprana de compuestos orgánicos volátiles (COV), manifestándose estos cambios químicos mucho antes de que aparecieran signos visuales de descomposición (como ablandamiento o cambios de color). Finalmente, el análisis comparativo determinó que solo los sensores MQ-3 (altamente sensible a alcoholes) y MQ-135 (sensible a dióxido de carbono y amoníaco) son realmente efectivos para alertar sobre el deterioro temprano en etapas poscosecha, mientras que los demás modelos evaluados no mostraron respuestas de utilidad práctica. |
| **Aporte** | Para fundamentar el desarrollo de este sistema inteligente en la recepción y almacenamiento del tomate, la investigación presente aporta un precedente metodológico esencial sobre el uso de sensores de gases de bajo costo. Específicamente, el artículo proporciona el criterio de selección técnico para este proyecto al validar que, dentro de los sensores evaluados, el modelo MQ-135 es el componente eficaz para registrar la liberación de CO2. Por consiguiente, la integración sinérgica del sensor MQ-135 junto con el análisis de color y textura por visión artificial optimiza la precisión del monitoreo en tiempo real, permitiendo identificar de forma temprana y objetiva el grado de frescura comercial del tomate en supermercados para evitar pérdidas en el punto de venta. |

## Artículo 03

| Campo | Detalle |
| :--- | :--- |
| **Título** | Sistema inteligente de predicción y alerta de deterioro de alimentos |
| **Título Original** | Smart Food Spoilage Prediction and Alert System |
| **Enlace de consulta** | https://secp.prabodhanamfoundation.org/jsn/index.php/ijnk/article/view/10 |
| **Descripción/Resumen** | Este artículo presenta el desarrollo de un sistema inteligente basado en el Internet de las Cosas (IoT) y algoritmos de Inteligencia Artificial enfocado en la predicción del deterioro de alimentos en tiempo real. El hardware del sistema utiliza un microcontrolador ESP32 acoplado a una matriz de sensores ambientales y químicos, que incluye el DHT22 (temperatura y humedad) y una serie de sensores de gases de la serie MQ, destacando el MQ-135 para la cuantificación de amoníaco (NH3), dióxido de carbono (CO2) y compuestos orgánicos volátiles (COV). Los autores establecieron umbrales analíticos de seguridad críticos (tales como CO2 > 1000 ppm y NH3 > 10 ppm que actúan como indicadores matemáticos de descomposición activa). Los datos recolectados se transmiten de forma inalámbrica a una plataforma en la nube, donde un modelo de Machine Learning analiza los patrones temporales para predecir la pérdida de frescura antes de que sea peligrosa. Finalmente, el sistema integra un módulo de alertas tempranas automatizadas que notifica los niveles de riesgo directamente a un panel de control móvil, permitiendo una gestión proactiva y escalable del almacenamiento. |
| **Aporte** | Para consolidar el diseño del sistema inteligente propuesto en la recepción y almacenamiento del tomate, la investigación de Venkataramanan et al. (2025) aporta un marco metodológico y tecnológico directo sobre la arquitectura IoT requerida. Su trabajo valida científicamente el uso del sensor MQ-135 como el componente idóneo para el monitoreo químico ambiental, demostrando su alta sensibilidad y capacidad para cuantificar de manera simultánea. Asimismo, el estudio fundamenta técnicamente la infraestructura de comunicación de datos al utilizar un microcontrolador para la captura sinérgica de variables químicas (MQ-135) y físicas (sensores de temperatura y humedad), transmitiendo la información hacia modelos en la nube encargados de predecir la pérdida de frescura. Por consiguiente, este antecedente justifica sólidamente tu propuesta, demostrando que la integración del sensor MQ-135 con técnicas de visión artificial permite configurar un sistema de alertas tempranas altamente automatizado y preciso para evitar pérdidas comerciales en supermercados. |

## Artículo 04

| Campo | Detalle |
| :--- | :--- |
| **Título** | Descripción general del aprendizaje profundo y la tecnología de detección no destructiva para la evaluación de la calidad de los tomates |
| **Título Original** | Overview of Deep Learning and Nondestructive Detection Technology for Quality Assessment of Tomatoes |
| **DOI** | 10.3390/foods14020286 |
| **Enlace de consulta** | https://pmc.ncbi.nlm.nih.gov/articles/PMC11764496/ |
| **Descripción/Resumen** | El artículo presenta una revisión sistemática donde se abordan los avances en técnicas de detección no destructiva combinadas con deep learning para la evaluación de calidad del tomate, discutiendo sus limitaciones actuales y perspectivas futuras para la industria comercial. Las técnicas se agrupan en tres categorías: caracterización mecánica, electromagnética y sensores electroquímicos. Se comparan sus características y se exploran distintos métodos de análisis de datos basado en deep learning. Su hallazgo principal evidencia un éxito significativo en la clasificación de la madurez del tomate mediante la visión artificial potenciada por deep learning, con precisiones superiores al 90%. Sin embargo, aunque es eficaz para identificar indicadores externos de madurez, presenta dificultades con los cambios internos de este alimento. Por su parte, los autores destacan que la espectroscopía Vis/NIR ha resultado efectiva para examinar atributos internos. En conclusión, esta investigación estructurada respalda el uso de visión artificial para clasificar el estado de madurez del tomate de forma no destructiva y sus avances continuos llevan a una perspectiva prometedora para la aplicación en la industria tomatera. |
| **Aporte** | El artículo aporta a este proyecto una base teórica y metodológica sólida sobre el empleo de técnicas no destructivas combinadas con inteligencia artificial para la evaluación de calidad del tomate. Los autores destacan que la integración de algoritmos de aprendizaje profundo ha permitido clasificar el estado de madurez del tomate a partir de imágenes con precisiones superiores al 90%. Adicionalmente, los autores señalan que la fusión de datos provenientes de múltiples sensores, procesada mediante modelos de inteligencia artificial, mejora significativamente el rendimiento predictivo, validando el enfoque multimodal propuesto en este proyecto. En conclusión, esta investigación estructurada respalda el uso de visión artificial para clasificar el estado de madurez del tomate de forma no destructiva, lo que apoya directamente la pertinencia tecnológica y la viabilidad del presente proyecto. |

## Artículo 05

| Campo | Detalle |
| :--- | :--- |
| **Título** | Monitorización de parámetros ambientales en cadenas de suministro de frutas y verduras frescas mediante tecnología de sensores y comunicación basada en el Internet de las Cosas |
| **Título Original** | Ambient Parameter Monitoring in Fresh Fruit and Vegetable Supply Chains Using Internet of Things-Enabled Sensor and Communication Technology |
| **DOI** | 10.3390/foods11121777 |
| **Enlace de consulta** | https://pmc.ncbi.nlm.nih.gov/articles/PMC9222862/ |
| **Descripción/Resumen** | Esta revisión analiza la tecnología de sensores IoT y comunicación inalámbrica en relación con las características específicas de calidad y deterioro de frutas y verduras frescas. Aborda los mecanismos de deterioro y sus implicancias para la calidad y vida útil, los parámetros ambientales relevantes y sus sensores IoT correspondientes, y las tecnologías de comunicación inalámbrica disponibles para el intercambio de datos en tiempo real. Entre sus hallazgos principales destacan los parámetros ambientales que mayor valor añadido aportan para la optimización de la calidad de alimentos, como lo son la temperatura, humedad relativa (HR), oxígeno y dióxido de carbono. Estas variables pueden ser monitoreadas por la tecnología de sensores IoT para su posterior procesamiento. |
| **Aporte** | La relevancia de este estudio radica en la sustentación científica de los parámetros para estimar la vida útil del tomate, y respalda el enfoque IoT con transmisión inalámbrica de datos a una app remota. |

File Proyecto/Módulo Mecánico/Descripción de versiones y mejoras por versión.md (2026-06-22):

# Descripción de Versiones y Mejoras del Hardware y Carcasa
## Proyecto: Sistema Inteligente para el Monitoreo y Clasificación de Tomate Fresco

Este documento detalla la evolución del diseño de la carcasa (CAD en Onshape), la integración de los componentes electrónicos, el sistema mecánico y de alimentación a través de sus tres versiones de desarrollo hasta consolidar el prototipo final funcional.

---

## 📐 Versión 1.0 - Diseño Inicial del Sistema

### Descripción General
Se desarrolló el primer prototipo digital de una carcasa destinada al monitoreo de las condiciones ambientales para la conservación de tomate fresco. El diseño fue realizado en **Onshape** considerando la integración de sensores y módulos electrónicos necesarios para la adquisición de datos y captura de imágenes.

### Componentes Integrados
* **ESP32:** Utilizado como unidad principal de procesamiento.
* **ESP32-CAM:** Dedicado exclusivamente para la captura y procesamiento de imágenes.
* **Sensor DHT22:** Para la medición precisa de temperatura y humedad ambiental.
* **Sensor MQ-135:** Para el monitoreo de la calidad del aire y detección de gases de descomposición.

### Características Implementadas
* Diseño geométrico de la carcasa principal.
* Modelado tridimensional de la tapa frontal y tapa trasera.
* Soportes internos dedicados para el anclaje de módulos electrónicos.
* Apertura y dimensionamiento específico para la óptica de la cámara ESP32-CAM.
* Rejillas de ventilación pasiva para la correcta circulación del aire hacia los sensores.
* Sistema de fijación y cierre mediante tornillos mecánicos.
* Base estructural sólida para el soporte general del sistema.

### Objetivos Alcanzados
* Definición de la estructura física y ergonomía base del dispositivo.
* Integración preliminar y espacial de los componentes electrónicos dentro del espacio tridimensional.
* Verificación dimensional del espacio disponible para el ensamblaje manual.
* Generación del primer prototipo CAD completamente funcional.

---

## ⚙️ Versión 2.0 - Integración de Alimentación, Iluminación y Sistema Mecánico

### Descripción General
Se realizaron mejoras sustanciales enfocadas en la autonomía eléctrica mediante alimentación externa, la homogenización de la iluminación para las técnicas de visión artificial y la incorporación de un mecanismo de accionamiento físico para automatizar el proceso de clasificación de los tomates.

### Mejoras Implementadas
* **Alimentación Externa:** Incorporación de un adaptador de corriente para la conexión directa a la red eléctrica.
* **Iluminación Controlada:** Integración de un sistema de iluminación mediante LED para estandarizar las capturas de imágenes de la cámara.
* **Optimización Térmica:** Adición de rejillas laterales de ventilación para mejorar el flujo de aire interno.
* **Distribución Espacial:** Rediseño y optimización de la ubicación interna de los componentes para evitar interferencias.
* **Soporte Electrónico:** Implementación de una baquelita perforada para el montaje, soldadura y organización rígida de los componentes electrónicos.

### Cambios de Componentes
* 🔴 *Se retiró* el ESP32 clásico utilizado inicialmente como controlador principal.
* 🟢 *Se incorporó* un servomotor para el accionamiento mecánico y desvío en la clasificación.
* 🔄 *Se unificó* el control en la placa **ESP32-S3-WROOM-1 CAM** para el procesamiento general, captura de imágenes y control de periféricos.

### Beneficios Obtenidos
* Mejor calidad y repetibilidad en la iluminación para los modelos de visión artificial.
* Mayor funcionalidad mecánica e interactividad automatizada mediante el servomotor.
* Mejor organización de los cables y de las conexiones eléctricas internas.
* Mayor facilidad para tareas de mantenimiento, desmontaje y montaje.
* Mejor disipación térmica activa/pasiva gracias a las nuevas rejillas de ventilación.

---

## 🏆 Versión 3.0 y Final - Prototipo Final Funcional

### Descripción General
Se desarrolló la versión definitiva y de producción del sistema, incorporando mejoras críticas de portabilidad en campo, flexibilidad en la alimentación, robustez en la protección del cableado, ergonomía de apertura rápida y control de encendido manual.

### Mejoras Implementadas
* **Portabilidad:** Integración de una Power Bank como fuente de alimentación portátil para pruebas en entornos agrícolas reales.
* **Conectividad Estándar:** Incorporación de conexión e interfaz mediante cable micro USB.
* **Control de Energía:** Adición de un interruptor físico ON/OFF para el control de encendido y apagado general del dispositivo.
* **Protección de Entrada:** Implementación de un prensaestopa para proteger, sellar y asegurar el paso del cableado de alimentación hacia el interior de la carcasa, evitando tirones mecánicos.
* **Sistema de Cierre Magnético:** Incorporación de imanes de neodimio de 10 mm para sustituir los tornillos en el sistema de cierre de la tapa.
* **Brazos de Desacople:** Diseño e impresión de brazos de apertura que permiten separar fácilmente la tapa venciendo la fuerza de atracción magnética de los imanes de neodimio.
* **Optimización de Potencia:** Redistribución balanceada de las líneas de energía interna.
* **Gestión de Cableado (*Cable Management*):** Organización final del cableado interno, mejorando la integración de las borneras y eliminando cruces de cables.
* **Interconexión Modular:** Inclusión de cables tipo macho y hembra para facilitar el intercambio rápido de módulos averiados.

### Componentes Incorporados (Lista Definitiva de Materiales)
1.  Power Bank (Alimentación portátil)
2.  Interruptor ON/OFF
3.  Prensaestopa plástico de seguridad
4.  Borneras de conexión atornillables
5.  Baquelita perforada de soporte
6.  Arnés de cables macho y hembra
7.  Servomotor de clasificación
8.  Sistema de iluminación LED integrado
9.  Imanes de neodimio de 10 mm (x4)
10. Brazos de apertura rápida para desacople magnético

### Beneficios Obtenidos
* **Máxima Autonomía:** Portabilidad completa para realizar pruebas directamente en los centros de acopio o invernaderos.
* **Robustez Mecánica:** Protección mecánica del cableado de entrada mediante el prensaestopa contra esfuerzos externos.
* **Acceso Rápido:** Cierre hermético y seguro de la carcasa sin necesidad de herramientas o tornillos adicionales.
* **Mantenimiento Eficiente:** Apertura rápida en segundos para inspección de componentes internos o calibración de sensores.
* **Seguridad Operacional:** Mejor experiencia de uso y seguridad eléctrica gracias al sistema de encendido independiente (Switch ON/OFF).
* **Validación Académica:** Diseño optimizado estéticamente y estructuralmente para pruebas finales y sustentaciones técnicas de alto nivel.

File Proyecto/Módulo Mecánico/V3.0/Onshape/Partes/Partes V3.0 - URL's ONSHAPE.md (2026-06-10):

https://cad.onshape.com/documents/3aaa6d63d6735c245e611fd3/w/1b99a54c1ed51bdaaa5a8ec2/e/d3a137b677472eb2c7eed6e2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

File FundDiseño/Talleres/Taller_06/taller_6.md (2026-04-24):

# MATRIZ DE DESK RESEARCH

| N° | Fuente | Autor/Institución | Año | Referencia | Estado de Tecnología encontrada | Exigencia o requisito identificado | Restricción o limitación | Función principal | Aplicacación al proyecto |
|:--:|:---|:---|:--:|:---|:---|:---|:---|:---|:---|
| 1 | ISO 22000:2018 | International Organization for Standardization (ISO) | 2018 | ISO 22000:2018 - Sistemas de gestión de la inocuidad de los alimentos Requisitos para cualquier organización en la cadena alimentaria | La tecnología y los estándares de esta versión de la norma están actualizados. Se enfoca en procesos, pensamiento de riesgos y mejora continua de los sistemas de gestión de inocuidad alimentaria. | Implementación de sistemas de gestión de seguridad alimentaria (SGIA) basados en los principios HACCP. | La norma es aplicable a todas las organizaciones de la cadena alimentaria, pero debe adaptarse a las características de cada organización. | Asegurar que los productos alimenticios sean seguros en todas las etapas de la cadena de suministro. | Esta norma ayuda a crear e implementar sistemas de seguridad alimentaria en cualquier tipo de organización que produzca, procese, distribuya o venda alimentos. | 
| 2 | Requisitos de calidad para el tomate: un ingrediente clave en la gastronomía peruana | INACAL (Instituto Nacional de Calidad) – Perú | 2024 | INACAL. (2024). NTP 011.712.2024. HORTALIZAS. Tomates. Requisitos. Lima: INACAL. | La norma establece requisitos de calidad basados en inspección visual y manual: los tomates deben estar intactos, limpios, sanos, libres de podredumbre, deterioro, plagas y olores extraños. Refieren parámetros de Humedad y Temperatura. | El tomate debe estar libre de podredumbre, deterioro y cualquier materia extraña visible. Además, las condiciones de almacenamiento deben ser: temperatura entre 8°C y 10°C y humedad relativa entre 80% y 85% para garantizar su conservación en buena calidad. | La inspección es visual y manual; no detecta deterioro temprano | Garantizar que los tomates comercializados en Perú cumplan con requisitos mínimos de calidad (integridad, limpieza, ausencia de podredumbre y plagas). | La norma exige que los tomates estén libres de podredumbre y deterioro. Además, los parámetros de almacenamiento (8-10°C, 80-85% HR) pueden ser incorporados como referencia para estimar la vida útil del tomate. |

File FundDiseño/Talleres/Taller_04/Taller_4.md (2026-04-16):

# Patentes
1. **Método y dispositivo para detectar la madurez de frutas y verduras.**
   - Resumen: La patente describe un dispositivo que utiliza sensores de color, grado de azúcar y dureza para detectar la madurez de frutas y verduras. Los datos
     son procesados por módulos internos y los resultados se muestran en un visualizador.
   - Código: CN114659918A
   - link: [ver patente](https://worldwide.espacenet.com/patent/search/family/082037969/publication/CN114659918A?q=detect%20maturity)
   - Imagen:

      <div align="center">
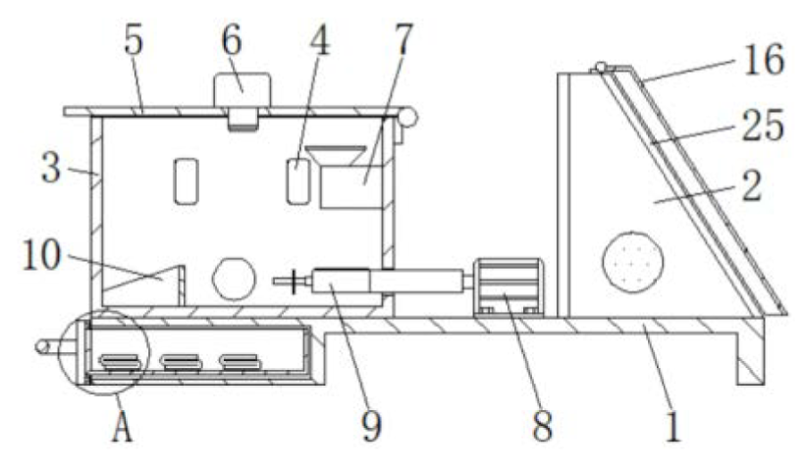
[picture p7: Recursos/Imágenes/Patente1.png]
         
      </div>

2. **MÁQUINA MEDIDORA DE PH PARA TOMATES MEDIANTE ACCIONAMIENTO ELECTROMECÁNICO Y VISIÓN ARTIFICIAL**
   - Resumen: La patente describe una máquina automatizada para medir el pH en tomates que utiliza visión                 artificial, sistemas electromecánicos y control automatizado para lograr mediciones precisas. Incorpora un          electrodo que mide pH y temperatura, junto con un sistema de calibración y limpieza que garantiza resultados        confiables. Además, emplea un cobot para posicionar los frutos correctamente, mejorando la exactitud del            análisis. En conjunto, esta tecnología está orientada al control de calidad en la industria alimentaria,            permitiendo evaluar la frescura y propiedades del tomate de manera eficiente.
   - Código:B08B 3/02
   - link: [ver patente](https://servicio.indecopi.gob.pe/portalSAE/Personas/tituloOIN.jsp)
   - Año: 2024
   - Expediente : 2447
   - Imagen:

      <div align="center">
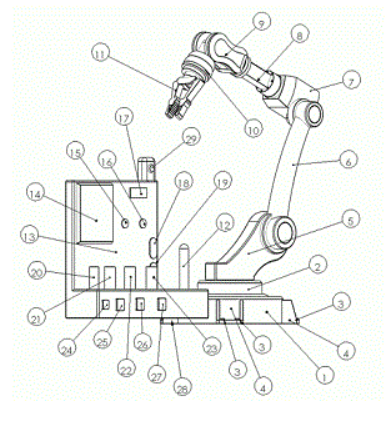
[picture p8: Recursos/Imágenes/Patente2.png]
         
      </div>

3. **DISPOSITIVO PARA EL RECONOCIMIENTO DE UN ALIMENTO Y PARA LA DETERMINACIÓN DE SU GRADO DE FRESCURA**
   - Resumen: La presente invención se refiere a un dispositivo para el reconocimiento de un alimento y para la determinación de su grado de frescura. Según la invención, el dispositivo comprende una carcasa externa, una unidad de procesamiento y control en comunicación de datos con el detector de gases, configurada para generar, a partir de dicha señal, una señal que indica el tipo de alimento presente en el recipiente y una señal que indica el grado de frescura de dicho alimento y la concentración de gases presentes dentro de dicha cavidad.
   - Código: WO2024201242A1
   - link: [ver patente](https://worldwide.espacenet.com/patent/search/family/086732523/publication/WO2024201242A1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)
   - Imagen:

      <div align="center">
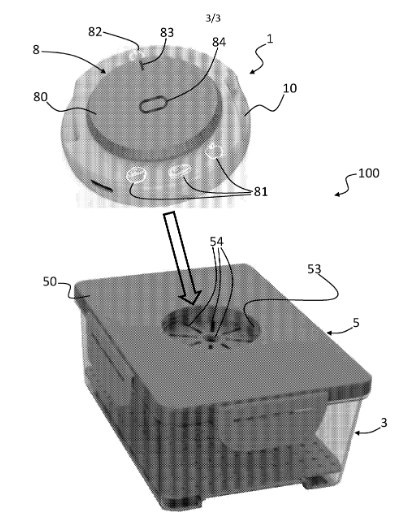
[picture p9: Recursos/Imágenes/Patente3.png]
         
      </div>

4. **SENSOR DE FRESCURA DEL PRODUCTO**
   - Resumen: La presente patente describe un sistema inteligente para monitorear la frescura de productos agrícolas mediante sensores de temperatura, gases y otros parámetros, integrados con un microcontrolador. El dispositivo permite el seguimiento en tiempo real durante almacenamiento y transporte, transmitiendo datos para evaluar el estado del producto. Además, optimiza el consumo de energía y utiliza una referencia inicial para detectar cambios y prevenir el deterioro.
   - Código: US11408820B1
   - link: [ver patente](https://patents.google.com/patent/US11408820B1/en)
   - Imagen:

<div align="center">
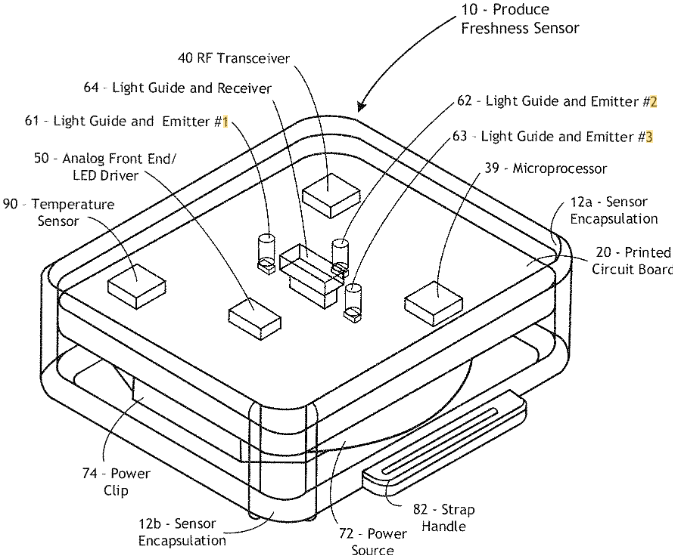
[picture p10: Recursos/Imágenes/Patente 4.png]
         
      </div>

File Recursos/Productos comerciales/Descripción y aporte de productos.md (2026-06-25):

# Cuadros Técnicos de Productos Comerciales

## Cuadro Técnico del Producto Comercial 01

| Campo | Detalle |
| :--- | :--- |
| **Producto** | Robovisión |
| **Nombre técnico** | Sistema automatizado de clasificación óptica de tomates mediante visión artificial e inteligencia artificial |
| **Enlace de consulta** | [https://robovision.ai/ucp-ai-powered-optical-tomato-sorter](https://robovision.ai/ucp-ai-powered-optical-tomato-sorter) |
| **Descripción/Resumen** | La solución Robovision Tomato Optical Sorter es un sistema basado en visión artificial e inteligencia artificial diseñado para la clasificación automática de tomates en procesos industriales. Este sistema analiza características visuales del fruto como el color, tamaño, forma y presencia de defectos, permitiendo determinar su grado de madurez y calidad sin causar daño al producto. El sistema puede ser entrenado para adaptarse a distintos tipos de tomate, lo que incrementa su precisión en la identificación de estados de frescura y defectos superficiales. Su aplicación principal se encuentra en líneas de procesamiento industrial donde se requiere clasificación rápida y automatizada de grandes volúmenes de producción. Sin embargo, esta solución está orientada principalmente a entornos industriales de alto volumen, lo que limita su aplicación en etapas tempranas de la cadena de suministro o en puntos de control intermedios, donde se requiere un análisis más integral del estado del producto, incluyendo condiciones ambientales. |
| **Aporte** | El sistema Robovision constituye un aporte importante como referencia tecnológica dentro del desarrollo del proyecto FreshTomato, ya que demuestra la aplicación real de la visión artificial y la inteligencia artificial en la clasificación automatizada de tomates en entornos industriales. Este sistema valida la viabilidad del uso de algoritmos de IA para evaluar la calidad del producto agrícola a partir de características visuales como el color, la forma y la presencia de defectos. Asimismo, Robovision permite comprender el nivel de avance de las soluciones existentes en el sector agroindustrial, sirviendo como base comparativa para el diseño de propuestas innovadoras. En ese sentido, su principal aporte al proyecto es establecer un punto de referencia tecnológico que respalda el uso de visión artificial, mientras que FreshTomato amplía este enfoque al integrar sensores ambientales y estimación de vida útil, logrando un análisis más completo del estado del tomate en diferentes etapas de la cadena de suministro. |

---

## Cuadro Técnico del Producto Comercial 02

| Campo | Detalle |
| :--- | :--- |
| **Producto** | Raytec Vision |
| **Nombre técnico** | Sistema automatizado de clasificación óptica de tomates mediante sensores multiespectrales y tecnología NIR |
| **Enlace de consulta** | [https://www.raytecvision.com/es/](https://www.raytecvision.com/es/) |
| **Descripción/Resumen** | Raytec Vision S.p.A. es una solución tecnológica orientada a la clasificación óptica de alimentos mediante el uso de cámaras de alta resolución y sensores de espectroscopia infrarroja cercana (NIR). Este sistema permite realizar un análisis más completo del tomate, evaluando tanto características externas como internas del producto sin necesidad de contacto físico. El sistema es capaz de detectar defectos como podredumbre, daños estructurales internos y alteraciones en la composición del fruto, lo que incrementa la precisión en los procesos de clasificación y selección de calidad dentro de la industria alimentaria. A diferencia de sistemas basados únicamente en visión superficial, esta tecnología permite una evaluación más profunda del estado del producto, mejorando la calidad del control en procesos industriales de clasificación. A pesar de sus ventajas, este tipo de sistemas presenta diversas limitaciones que restringen su aplicación en contextos más flexibles o de pequeña y mediana escala. Como Alto costo de implementación, debido al uso de sensores especializados y cámaras industriales de alta precisión, su orientación principalmente es industrial, lo que limita su uso en etapas intermedias de la cadena de suministro como recepción o puntos de venta y requiere infraestructura especializada |
| **Aporte** | El sistema Raytec Vision aporta al proyecto FreshTomato como un referente de tecnología avanzada en la inspección y clasificación de tomates mediante sensores multiespectrales y espectroscopia de infrarrojo cercano (NIR). Su principal aporte es demostrar que es posible evaluar la calidad del tomate de manera no destructiva, es decir, sin necesidad de cortarlo, identificando tanto características externas como internas como podredumbre, daños estructurales y alteraciones en su composición. Esto valida técnicamente la idea del proyecto FreshTomato, ya que respalda el uso de sistemas automáticos para determinar el estado del producto agrícola con mayor precisión que los métodos tradicionales. Además, permite comprender cómo la industria alimentaria emplea sensores avanzados y visión artificial para mejorar la clasificación de alimentos, sirviendo como base de referencia para el desarrollo de soluciones más accesibles. En este sentido, Raytec Vision aporta al proyecto principalmente como sustento tecnológico y validación del enfoque de evaluación integral de la calidad del tomate, aunque en un nivel industrial de mayor complejidad. |

---

## Cuadro Técnico del Producto Comercial 03

| Campo | Detalle |
| :--- | :--- |
| **Producto** | TOMRA Sentinel II |
| **Nombre técnico** | Sistema de clasificación óptica de tomates y otros productos agrícolas mediante visión artificial, sensores de alta resolución e iluminación LED pulsada.|
| **Enlace de consulta** | [https://www.tomra.com/es-es/food/machines/sentinel-ii] |
| **Descripción/Resumen** | TOMRA Sentinel II es una máquina de clasificación óptica diseñada para la inspección y selección automática de tomates, melocotones, papas y otros productos agrícolas. El sistema utiliza cámaras de alta resolución, sensores ópticos e iluminación LED pulsada para detectar defectos, decoloraciones, pudrición, daños superficiales y materiales extraños presentes en la línea de producción. Los productos son inspeccionados mientras se desplazan por una banda transportadora y, mediante mecanismos automáticos de expulsión, se separan aquellos que no cumplen con los criterios de calidad establecidos. Además, la plataforma permite mantener una calidad uniforme del producto, optimizar el rendimiento de producción y reducir la necesidad de clasificación manual. Está orientada principalmente a plantas procesadoras y empacadoras de gran escala, con capacidades de trabajo que pueden alcanzar entre 40 y 200 toneladas por hora. |
| **Aporte** | TOMRA Sentinel II aporta al proyecto FreshTomato como una referencia tecnológica en la clasificación automatizada de tomates mediante visión artificial. Su sistema demuestra cómo el uso de cámaras y algoritmos de procesamiento de imágenes permite identificar defectos y evaluar la calidad del producto de manera objetiva, reduciendo la dependencia de la inspección manual. Este producto comercial sirvió como base para comprender las tecnologías empleadas en la industria alimentaria y permitió identificar oportunidades de mejora, como la incorporación de sensores de gases, temperatura y humedad para estimar la vida útil restante del tomate. Asimismo, evidencia la necesidad de desarrollar alternativas más accesibles y de menor costo para mercados, supermercados y pequeños productores. |

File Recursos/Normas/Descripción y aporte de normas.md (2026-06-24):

# Cuadros Técnicos de las Normas del Proyecto

Este documento presenta los cuadros técnicos de las normas aplicadas al proyecto.

---

## Cuadro Técnico de la Norma 01

| Componente | Detalle |
| :--- | :--- |
| **Norma** | **ISO 22000:** Gestión de la seguridad alimentaria |
| **Descripción / Resumen** | El ISO 22000 es la norma internacional que unifica los requisitos para un Sistema de Gestión de la Inocuidad de los Alimentos, aplicable a cualquier organización de la cadena de suministro, desde el productor primario hasta el distribuidor. Su estructura combina la gestión empresarial global con los principios científicos del HACCP (Análisis de Peligros y Puntos Críticos de Control) y los Programas de Prerrequisitos (PPR), asegurando un entorno de trabajo higiénico y seguro. A través de un enfoque basado en riesgos y un doble ciclo de mejora continua (PHVA), la norma exige el control estricto de los peligros biológicos, químicos y físicos, optimizando la comunicación interactiva entre todos los eslabones del sector y garantizando la trazabilidad total del producto. Su objetivo final no es la calidad comercial, sino la mitigación absoluta de riesgos para asegurar que el alimento no cause daño al consumidor. |
| **Aporte** | El aporte de la presente norma es que exige que los materiales y componentes de nuestro dispositivo en contacto con el entorno de los tomates frescos garanticen altos estándares de higiene, evitando la migración de contaminantes. Asimismo, a partir de lo mencionado, la estructura geométrica del sistema debe presentar un diseño higiénico que impida el estancamiento de fluidos, resista la corrosión por humedad y facilite los procesos de limpieza y desinfección, mitigando la proliferación de peligros biológicos o químicos que pongan en riesgo la salud del consumidor final. |

---

## Cuadro Técnico de la Norma 02

| Componente | Detalle |
| :--- | :--- |
| **Norma** | **ISO 42001:** Sistemas de Gestión de la Inteligencia Artificial |
| **Descripción / Resumen** | La ISO/IEC 42001:2023 establece los requisitos para implantar, mantener y mejorar continuamente un Sistema de Gestión de Inteligencia Artificial (SGIA) en las organizaciones. Su propósito es equilibrar la innovación tecnológica con la mitigación de riesgos éticos y operativos, asegurando que el desarrollo y uso de la IA se realice de manera responsable, transparente y auditable. |
| **Aporte** | El sistema integra algoritmos de Machine Learning para optimizar el procesamiento de datos de clasificación de tomates. Al ser un estándar de gestión organizacional y no una certificación de software, su aporte metodológico al proyecto radica en guiar el diseño de un marco de desarrollo ético y confiable. Esto se traduce en la exigencia de implementar protocolos estrictos de validación, documentación y control de sesgos en los datos de entrenamiento del modelo predictivo. De esta manera, se garantiza que las predicciones generadas por el algoritmo sean técnicamente reproducibles, seguras ante fallos y completamente auditables en su toma de decisiones. |

---

## Cuadro Técnico de la Norma 03

| Componente | Detalle |
| :--- | :--- |
| **Norma** | **ISO 12100:** Seguridad de las máquinas |
| **Descripción / Resumen** | La ISO 12100 es la norma internacional que establece los principios generales para el diseño seguro de maquinaria, enfocada en la evaluación y reducción de riesgos. Define un proceso iterativo en tres etapas (diseño inherentemente seguro, medidas técnicas de protección e información para el uso) para eliminar o mitigar los peligros potenciales para el operador durante todo el ciclo de vida del equipo. |
| **Aporte** | El aporte de esta norma a nuestro proyecto es que nos ayudó a que el dispositivo contará con un diseño cerrado, ergonómico y libre de aristas cortantes para facilitar la manipulación segura. El diseño físico se fundamenta en los principios de la norma ISO 12100, la cual aporta una metodología sistemática para la identificación de peligros y la reducción de riesgos mecánicos desde la etapa de bocetos. El aporte específico del estándar radica en guiar la integración de medidas de protección inherentes, asegurando que el acoplamiento de las partes o circuitos del sistema no represente un peligro para el usuario. |

---

## Cuadro Técnico de la Norma 04

| Componente | Detalle |
| :--- | :--- |
| **Norma** | **Decreto Supremo N°007-98-S.A:** Vigilancia y Control Sanitario |
| **Descripción / Resumen** | El Decreto Supremo N° 007-98-SA es el Reglamento sobre Vigilancia y Control Sanitario de Alimentos y Bebidas en el Perú. Regula las condiciones sanitarias, de higiene y de inocuidad que deben cumplir la producción, fabricación, transporte y comercialización de productos alimenticios. Específicamente, en sus capítulos de condiciones de establecimientos y equipos, prohíbe el uso de materiales que puedan transferir sustancias tóxicas, alteren las características organolépticas del alimento o dificulten la desinfección. |
| **Aporte** | El sistema Fresh Tomato será construido bajo criterios de viabilidad logística nacional y ensamblaje local, garantizando que los materiales en contacto con los tomates frescos o su entorno inmediato no alteren el producto. El aporte directo del Decreto Supremo N° 007-98-SA al proyecto radica en establecer el marco legal obligatorio de inocuidad para el diseño de la estructura física del dispositivo. Cumpliendo con este reglamento, la carcasa cerrada y los componentes se fabricarán con materiales sanitarios no porosos, resistentes a la corrosión y aptos para el sector alimentario, evitando la transferencia de contaminantes químicos o biológicos. |

---

## Cuadro Técnico de la Norma 05

| Componente | Detalle |
| :--- | :--- |
| **Norma** | **IEC 61010-1:** Requisitos de seguridad para equipos eléctricos de medición, control y uso en laboratorio |
| **Descripción / Resumen** | La IEC 61010-1 es la norma global que especifica los requisitos de seguridad eléctrica y operativa para equipos electrónicos de control, medición y laboratorio. Su objetivo fundamental es garantizar que, tanto en condiciones normales como en caso de una falla interna, el dispositivo no represente un peligro de electrocución, cortocircuito, incendio o liberación de energía peligrosa para el operador que lo manipula. |
| **Aporte** | A partir de esta norma, el sistema de monitoreo adoptará un diseño compacto y liviano que optimice su transporte y reubicación manual, integrando de forma conjunta los criterios de seguridad estructural de la norma ISO 12100 y de seguridad eléctrica de la IEC 61010-1. Asimismo, el aporte metodológico de este estándar IEC radica en normar la protección del circuito electrónico del dispositivo frente a condiciones críticas del entorno. Su implementación técnica exige un aislamiento adecuado de las conexiones, un cableado interno seguro y la mitigación de riesgos de sobrecarga o cortocircuito durante el encendido. De este modo, se garantiza que las labores de traslado, conexión y manipulación directa por parte de los operadores se realicen de manera totalmente segura, previniendo accidentes eléctricos y resguardando la integridad de los componentes de medición. |

---

## Cuadro Técnico de la Norma 06

| Componente | Detalle |
| :--- | :--- |
| **Norma** | **ISO 17025:** Requisitos generales para la competencia de los laboratorios de ensayo y calibración |
| **Descripción / Resumen** | La ISO/IEC 17025:2017 es la norma internacional que establece los requisitos generales para la competencia técnica, la imparcialidad y la operación consistente de los laboratorios de ensayo y calibración. Su propósito es asegurar que los laboratorios generen resultados válidos, técnicamente confiables y con trazabilidad metrológica hacia el Sistema Internacional de Unidades (SI), permitiendo que sus certificados sean aceptados globalmente. |
| **Aporte** | El sistema operará de manera continua en áreas de recepción de supermercados, donde enfrentará variaciones ambientales de temperatura, humedad y concentración de CO2. El aporte fundamental de la norma ISO/IEC 17025:2017 al proyecto radica en asegurar la validez científica y la trazabilidad de los datos recolectados por los sensores ante estas fluctuaciones mediante una previa calibración. Esto garantiza que las lecturas utilizadas por el algoritmo de predicción de vida útil de los tomates no posean desviaciones fuera de los márgenes tolerables, blindando la precisión del modelo matemático frente a revisiones técnicas. |

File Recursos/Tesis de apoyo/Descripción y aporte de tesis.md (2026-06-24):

# Cuadros Técnicos de las Tesis del Proyecto

Este documento presenta los cuadros técnicos de las tesis identificadas para el proyecto.

---

## Cuadro Técnico de la Tesis 01

| Componente | Detalle |
| :--- | :--- |
| **Título** | Planteamiento Estratégico del Tomate en el Perú |
| **Autor(es)** | Moisés Córdova Peña, Renzo Pinasco Alegre, Giannina Pizarro Chirinos y Teófilo Quiñones Jara |
| **Institución** | Pontificia Universidad Católica del Perú (PUCP) |
| **Descripción / Resumen** | La tesis *Planeamiento Estratégico del Tomate en el Perú* realiza un análisis integral de la industria tomatera peruana, evaluando aspectos productivos, económicos, tecnológicos y ambientales que influyen en su desarrollo. El estudio identifica las principales regiones productoras del país, como Ica, Lima y Arequipa, además de examinar factores relacionados con la productividad, competitividad, comercialización y exportación del tomate. Asimismo, analiza las limitaciones existentes en la cadena productiva, incluyendo problemas de conservación, control fitosanitario, transporte y almacenamiento. Finalmente, propone estrategias orientadas a mejorar la sostenibilidad, eficiencia y crecimiento del sector tomatero peruano, fortaleciendo su participación en los mercados nacionales e internacionales. |
| **Aporte** | Esta tesis proporciona información relevante sobre la problemática del tomate en el Perú, especialmente en relación con las pérdidas poscosecha, las dificultades de conservación y la necesidad de mejorar la calidad del producto durante su comercialización. Los hallazgos del estudio respaldan la importancia de implementar soluciones tecnológicas que permitan monitorear el estado de los tomates de forma objetiva y en tiempo real. En este contexto, el proyecto *FreshTomato* se beneficia de esta investigación al proponer una herramienta basada en visión artificial, sensores ambientales e inteligencia artificial para clasificar tomates según su nivel de frescura y estimar su vida útil, contribuyendo a la reducción del desperdicio y a una gestión más eficiente de la cadena de suministro. |

---

## Cuadro Técnico de la Tesis 02

| Componente | Detalle |
| :--- | :--- |
| **Título** | Planteamiento Estratégico del Tomate en el Perú |
| **Autor(es)** | Oscar David Barrio de Mendoza Salas, Danny Joel Pizarro Díaz, Cinthya Vanessa Vásquez Lozano |
| **Institución** | Pontificia Universidad Católica del Perú (PUCP) |
| **Descripción / Resumen** | La tesis analiza la gestión de inventarios de productos perecibles en supermercados, centrándose en la reducción de mermas y pérdidas ocasionadas por deficiencias en la planificación del abastecimiento. El estudio identifica problemas relacionados con el deterioro de productos, exceso o falta de inventario, limitaciones en los sistemas de información y dificultades en la gestión de la cadena de suministro. Asimismo, propone una matriz de indicadores para mejorar el control de variables críticas y optimizar la toma de decisiones en el manejo de productos perecibles, contribuyendo a una gestión más eficiente y sostenible. |
| **Aporte** | Esta tesis aporta conocimientos sobre la gestión de productos perecibles y la importancia de monitorear variables que influyen en su deterioro y vida útil. Además, destaca cómo las pérdidas económicas y las mermas pueden originarse por información insuficiente o una evaluación inadecuada del estado de los productos. Estos hallazgos respaldan el desarrollo de *FreshTomato*, ya que el proyecto busca proporcionar información objetiva sobre la frescura del tomate mediante visión artificial, sensores ambientales e inteligencia artificial, permitiendo mejorar la toma de decisiones, reducir desperdicios y optimizar la gestión de inventarios en supermercados. |

---

## Cuadro Técnico de la Tesis 03

| Componente | Detalle |
| :--- | :--- |
| **Título** | Diseño de un sistema de control de calidad para tomates cherry usando biosensores y Deep Learning con GoogleNet en Matlab |
| **Autor(es)** | Álvaro Santiago Garay Gutiérrez, Alber Steven Rojas Ynga |
| **Institución** | Universidad Ricardo Palma – Facultad de Ingeniería, Escuela Profesional de Ingeniería Mecatrónica, Lima, Perú |
| **Descripción / Resumen** | La investigación desarrolló un sistema automatizado para el control de calidad de tomates cherry mediante el uso de biosensores, visión artificial y Deep Learning con la arquitectura GoogleNet en Matlab. El sistema permite monitorear los tomates, detectar plaguicidas, procesar imágenes para identificar su estado y enviar la información a la plataforma IoT ThingSpeak para su visualización y análisis en tiempo real. Se obtuvo una precisión de 99,37 % en la clasificación de imágenes de tomates cherry. |
| **Aporte** | Esta tesis aporta a *FreshTomato* porque demuestra la viabilidad del uso de la inteligencia artificial y la visión artificial para evaluar la calidad de los tomates. Además, proporciona una referencia sobre la integración de sensores, procesamiento de imágenes y plataformas IoT para monitorear productos agrícolas. Estos conceptos sirven como base para el desarrollo de *FreshTomato*, permitiendo implementar un sistema de clasificación automática y estimación del estado de frescura de los tomates mediante tecnologías inteligentes. |

---

## Cuadro Técnico de la Tesis 04

| Componente | Detalle |
| :--- | :--- |
| **Título** | Gestión de inventarios y la merma de productos perecederos en Hipermercados Tottus Oriente S.A.C. Precio Uno, Iquitos |
| **Autor(es)** | Adrian Lopez Espinoza, Denis Rolando Lopez Espinoza |
| **Institución** | Universidad Científica del Perú |
| **Descripción / Resumen** | La investigación analiza la relación entre la gestión de inventarios y las mermas de productos perecederos en Hipermercados Tottus Oriente S.A.C. Precio Uno, en Iquitos. El estudio identificó que las pérdidas de productos perecederos se originan por deficiencias en el almacenamiento, la rotación de productos, la planificación de la demanda y el control de inventarios. Asimismo, resalta la importancia de implementar estrategias y sistemas que permitan monitorear adecuadamente los productos para reducir las pérdidas económicas. |
| **Aporte** | La investigación aporta conocimientos sobre la gestión de inventarios y las causas que generan mermas en productos perecederos, resaltando la importancia del control, almacenamiento y monitoreo adecuado para reducir pérdidas económicas. Asimismo, demuestra que la implementación de estrategias y sistemas de seguimiento contribuye a optimizar los procesos logísticos, mejorar la conservación de los productos y disminuir el desperdicio de alimentos en los establecimientos comerciales. |

---

## Cuadro Técnico de la Tesis 05

| Componente | Detalle |
| :--- | :--- |
| **Título** | Vida útil de tomate (Solanum lycopersicum L. var. Sheila Victory F1) cosechado en dos estados de madurez y almacenados en diferentes tiempos y temperaturas |
| **Autor(es)** | María Yovani Irigoín Lara |
| **Institución** | Universidad Nacional de Cajamarca – Facultad de Ciencias Agrarias, Escuela Profesional de Ingeniería en Industrias Alimentarias |
| **Descripción / Resumen** | La investigación tuvo como objetivo determinar la vida útil del tomate variedad Sheila Victory F1 en dos estados de madurez y bajo diferentes condiciones de almacenamiento. Se evaluaron características fisicoquímicas como peso, pH, grados Brix, color y textura, concluyendo que el almacenamiento a 8 °C permitió prolongar la vida útil del tomate y conservar mejor sus propiedades de calidad. |
| **Aporte** | Esta tesis aporta al proyecto porque proporciona información sobre cómo la temperatura, el tiempo de almacenamiento y el estado de madurez influyen en la conservación y calidad del tomate. Además, ofrece una referencia sobre los cambios fisicoquímicos que experimenta el fruto durante su almacenamiento, permitiendo comprender mejor los factores relacionados con la frescura y la vida útil. Estos conocimientos sirven como base para desarrollar sistemas inteligentes capaces de monitorear el estado del tomate y estimar su tiempo de conservación mediante tecnologías de análisis y clasificación. |

---

## Cuadro Técnico de la Tesis 06

| Componente | Detalle |
| :--- | :--- |
| **Título** | Implementación de filtros digitales en controladores digitales de señal |
| **Autor(es)** | José Andrés Cordero García |
| **Institución** | Universidad del Azuay – Facultad de Ciencia y Tecnología, Escuela de Ingeniería Electrónica, Cuenca, Ecuador |
| **Descripción / Resumen** | La investigación estudia los principios del procesamiento digital de señales y el diseño de filtros digitales aplicados en controladores digitales de señal (DSP). El trabajo explica las técnicas de filtrado utilizadas para mejorar la calidad de las señales y reducir interferencias o ruido en los datos obtenidos por sistemas electrónicos. Asimismo, desarrolla aplicaciones prácticas mediante el uso de microcontroladores especializados y herramientas como MATLAB, permitiendo la adquisición, procesamiento y análisis de señales de manera eficiente. La tesis demuestra la importancia del procesamiento digital en sistemas de medición y control que requieren resultados precisos y confiables. |
| **Aporte** | Esta tesis aporta al proyecto porque proporciona fundamentos sobre el procesamiento digital de señales y las técnicas de filtrado necesarias para mejorar la calidad de los datos obtenidos por sensores. Además, ofrece una referencia sobre la implementación de algoritmos en sistemas embebidos y el tratamiento de información proveniente de dispositivos electrónicos. Estos conocimientos son útiles para optimizar la precisión y confiabilidad de las mediciones realizadas por los sensores del sistema, permitiendo obtener resultados más estables y mejorar el proceso de análisis y clasificación de los tomates. |

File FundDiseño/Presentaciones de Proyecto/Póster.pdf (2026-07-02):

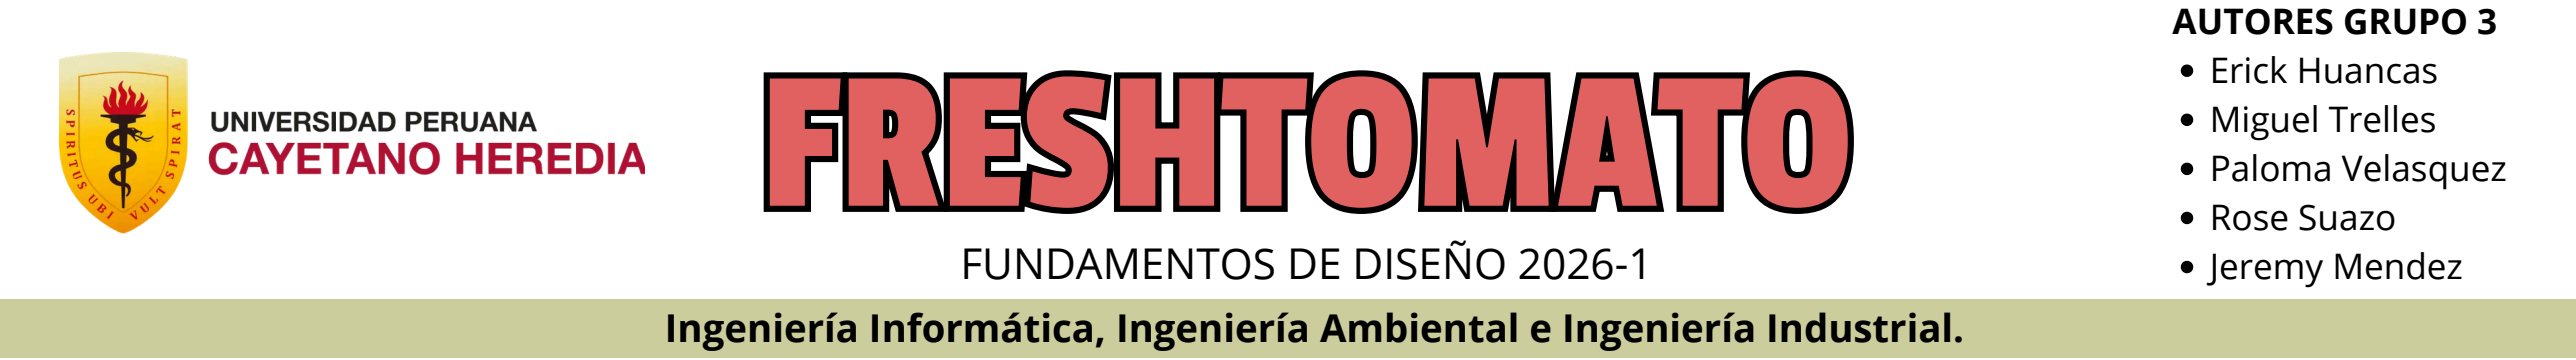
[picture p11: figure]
FUNDAMENTOS DE DISEÑO 2026-1; FFRREESSHHTTOOMMAATTOO; AUTORES GRUPO 3 Erick Huancas Miguel Trelles Paloma Velasquez Rose Suazo Jeremy Mendez

Parámetro | Valor
Imágenes del conjunto de datos | 801
Entrenamiento | 70%
Validación | 15%
Pruebas | 15%
Exactitud del modelo | 99.3%

Identificación automática del estado del tomate mediante visión computacional e inteligencia artificial.
Estimación del tiempo durante el cual el tomate permanecerá en buen estado. Monitoreo remoto mediante una plataforma web.
Generación de alertas para la gestión de inventarios mediante la estrategia FEFO. Diseño portátil para su implementación en supermercados.

Conclusiones

### Historial de evaluaciones

Diseñar e implementar un sistema inteligente que identifique en tiempo real el estado del tomate (buen estado o deteriorado) y estime el tiempo durante el cual permanecerá en buen estado, mediante sensores, visión computacional e inteligencia artificial.

## INTRODUCCIÓN

REFERENCIAS BIBLIOGRÁFICAS:

Ingeniería Informática, Ingeniería Ambiental e Ingeniería Industrial.

## METODOLOGíA

El tomate es una de las hortalizas más consumidas en el Perú [1]. Debido a su alta perecibilidad, presenta pérdidas durante el almacenamiento y la comercialización [2]. Se desarrolló un sistema inteligente que identifica en tiempo real el estado del tomate (buen estado o deteriorado) y estima el tiempo durante el cual permanecerá en buen estado.

## OBJETIVOS

Objetivo general:

## PROPUESTA DE INNOVACIÓN

Aspectos Innovadores:

INVESTIGACIÓN
BIBLIOGRÁFICA

## RESULTADOS

INTEGRACION ELECTRONICA

RECOLECCIÓN DE DATOS

DISEÑO DEL
SISTEMA

Tabla 1. Principales causas de pérdida poscosecha del tomate en el Perú.

Fuente: [3].

Objetivos específicos:
Diseñar la estructura del sistema inteligente.
Registrar variables ambientales (temperatura, humedad y concentración de gases). Capturar imágenes del tomate desde diferentes ángulos.
Identificar mediante inteligencia artificial si el tomate se encuentra en buen estado o deteriorado.
Estimar el tiempo durante el cual el tomate permanecerá en buen estado.
Visualizar los resultados en tiempo real mediante una plataforma web.

### Resultado de Evaluación

El sistema identificó el estado del tomate con una exactitud del 99.3 %.
El sistema estimó el tiempo durante el cual el tomate permanecerá en buen estado. La integración de sensores e inteligencia artificial permitió automatizar la evaluación y visualizar los resultados en una plataforma web.
CONCLUSIONES | RECOMENDACIONES

LECCIONES APRENDIDAS

La integración progresiva de los componentes electrónicos y el software facilitó la validación del prototipo.
La planificación, el trabajo colaborativo y las pruebas continuas permitieron mejorar el desempeño del sistema.

Adaptar el prototipo para evaluar automáticamente varios tomates de forma consecutiva.
Incorporar una cámara de mayor resolución para mejorar la calidad de las imágenes.
Ampliar la base de datos de imágenes para mejorar el desempeño del modelo de inteligencia artificial.
1. Ministerio de Desarrollo Agrario y Riego (marca el autor como corporativo haciendo clic en el ícono de la persona al lado del campo Autor y seleccionando «Autor corporativo» o «Usar un solo campo», según tu versión). Plataforma del Estado Peruano [Internet]. Lima, Perú: Gobierno del Perú; 2024. MIDAGRI promueve el consumo de frutas y verduras como principal fuente para la alimentación saludable. Disponible en: https://www.gob.pe/institucion/midagri/noticias/944364-midagri-promueve-el-consumo-de-frutas-y-verduras-como-principal-fuente-para-la-alimentacion-saludable (https://www.zotero.org/google-docs/?jnMcc8)
2. Food and Agriculture Organization of the United Nations (FAO). Prevention of Post-Harvest Food Losses: Fruits, Vegetables and Root Crops – A Training Manual [Internet]. Rome: FAO; 1989 [citado 30 de junio de 2026]. Disponible en: https://www.fao.org/4/T0073E/T0073E01.htm (https://www.zotero.org/google-docs/?jnMcc8)
3. Irigoín Lara, María Yovani. Evaluación de la vida útil de tomate variedad Sheila Victory F1 en dos estados de madurez y dos temperaturas de almacenamiento (o el título completo que aparece en la portada) [Tesis de pregrado]. [Cajamarca, Perú]: Universidad Nacional de Cajamarca; 2024. (https://www.zotero.org/google-docs/?jnMcc8)

ENTRENAMIENTO DEL MODELO DE INTELIGENCIA ARTIFICIAL

INTEGRACIÓN | DE | LA
PLATAFORMA WEB

7
VALIDACIÓN DEL PROTOTIPO
Resultados del entrenamiento del modelo | Prototipo funcional

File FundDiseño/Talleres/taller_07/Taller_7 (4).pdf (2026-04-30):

## UNIVERSIDAD PERUANA CAYETANO HEREDIA

### Facultad de Ciencias e Ingeniería

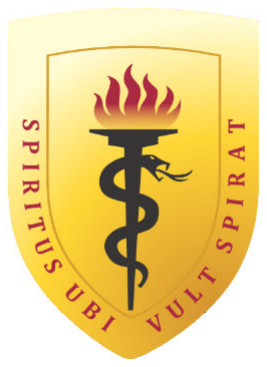
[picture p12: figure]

## INFORME TÉCNICO DEL PROYECTO

## Dispositivo embebido de estimación de vida útil y clasificación del estado de madurez del tomate mediante sensores ambientales y visión artificial

## Fundamentos de Diseño

### Grupo: 3

### Integrantes:

### Huancas Bereche, Erick Emilio Ruiz Trelles Miguel Santos Méndez Ponce De León Jeremy Suazo Davila, Rose Angel Velasquez Saforas, Paloma Fernanda

### Profesores a cargo:

Da Silva, Jose Luis
Flores Robles, Domingo Vladimir Mugaburu Celi, Marco Antonio Venancio Huerta, Julissa Elvira

Lima - Perú
2026

ÍNDICE

### 1. Lista de Exigencias

Lista de Exigencias

Proyecto | Fecha: 29/04/2026

Dispositivo embebido de estimación de vida útil y clasificación del estado de madurez del tomate mediante sensores ambientales y visión artificial

Revisado:

Cliente | -Da Silva, Jose Luis -Flores Robles, Domingo Vladimir -Mugaburu Celi, Marco Antonio -Venancio Huerta Julissa Elvira | Elaborado por: -Huancas Bereche, Erick Emilio -Ruiz Trelles Miguel Santos -Méndez Ponce De León Jeremy -Suazo Davila, Rose Angel -Velasquez Saforas, Paloma Fernanda
Fecha | Deseo o exigencia | Descripción | Responsable

Cambios

17/04/26 | | Función Principal | Todos
| E | El dispositivo debe clasificar el tomate en dos categorías(buen estado o mal estado) y estimando su tiempo de vida útil restante .
| D | Estimar su tiempo de vida útil en un rango de 1 a 7 días, sin dañar el producto.
17/04/2026 | | Geometría | M.T
| E | El tamaño en conjunto de la máquina, tomando en cuenta los componentes físicos, así como los distintos componentes de hardware e interfaz física será una caja con base de 20x20cm y una altura de 15cm.
17/04/2 | | Materia | M.T
| E | Materia de ingreso: Tomate (Solanum lycopersicum L.) destinado a recepción, almacenamiento y comercialización en supermercados.(1) (https://www.zotero.org/google-docs/?y11X46)

| E | Se espera que el sistema tenga una capacidad de evaluación de solo un fruto de tomate (Solanum lycopersicum L.) por ciclo de monitoreo. El tomate presenta un peso promedio de 110 a 180 gramos por unidad, dependiendo de su estado de madurez.(2) (https://www.zotero.org/google-docs/?CDEU2C)
| D | El material de salida será la clasificación del tomate (Solanum lycopersicum L.) en categorías de “Buen estado” y “Mal estado” según su estado de conservación y nivel de deterioro.
19/04/2026 | | Energía | M.D
| E | El módulo podrá alimentarse mediante una fuente externa como una batería o un powerbank y deberá optimizar su consumo tanto en estado activo como en reposo.
19/04/2026 | | Señales | M.T
| E | Señales de entrada: -Energía eléctrica -Señal de encendido/apagado -Señal de la captura de la imagen -Señal del sensor de temperatura y humedad -Señal del sensor de CO2 Señales de salida: -Energía calorífica -Señal de nivel de temperatura, humedad y concentraciones de gases -Señal de nivel de temperatura, humedad y concentraciones de gases del tomate -Señal de estimación de tiempo de vida útil del tomate
20/04/2026 | | Control | E.H
| E | El sistema de control del dispositivo debe permanecer estable en todas las etapas de funcionamiento: desde la activación del sistema hasta la obtención del resultado de la clasificación. Se debe controlar el flujo de operación, asegurando que la secuencia (encendido de iluminación, captura de imagen, lectura de sensores, procesamiento y emisión del resultado) se ejecute en el orden correcto y sin interrupciones. Además el sistema debe ser capaz de reiniciar la operación para evaluar un nuevo tomate sin necesidad de reiniciar el dispositivo

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
l. A

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
e. L

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
s. 20/04/26

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
e. E

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
s. E

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
l. A

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
e. La comunicación entre sus componentes debe ser estable y sin interferencias, permitiendo la integración con sistemas externos para el almacenamiento | y análisis de datos. Finalmente, debe facilitar la visualización de resultados para la toma de decisiones. 20/04/26 | Seguridad

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
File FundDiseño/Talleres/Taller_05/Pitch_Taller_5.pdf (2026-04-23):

Historia:

¿Sabías que en Perú el 27% de las pérdidas de tomate son por podredumbre, mientras que 17 millones de peruanos pasan hambre? Somos el Equipo 03 del curso Fundamentos de Diseño, conformado por estudiantes de Ingeniería Ambiental, Informática e Industrial. Nuestro proyecto, FreshTomate, nace de una escena que vimos en un supermercado de Lima. Don Carlos, encargado del área de frutas y verduras, acababa de botar un cuarto de tonelada de tomates a la basura. "Los recibí ayer", nos dijo, "pero esta mañana ya estaban blandos". Esa pérdida le costó 800 soles al supermercado.

Problema:

Pero el problema no termina en don Carlos. Esa misma escena se repite todos los días en cientos de supermercados. En Lima, los métodos actuales son subjetivos. El personal aprieta el tomate o lo mira. Un tomate puede verse bien por fuera y estar podrido por dentro. Los supermercados usan el sistema FIFO ("primero en entrar, primero en salir"), que asume que todos los tomates son iguales. Pero no lo son. Algunos lotes tienen más gas etileno la hormona de la maduración y se echan a perder más rápido. Las soluciones que existen cuestan más de 5 mil dólares. Mientras tanto, esos tomates podridos generan metano, un gas que calienta el planeta 80 veces más que el CO₂.

Solución y Propuesta de valor

Actualmente, los supermercados gestionan la recepción de tomate por orden de llegada, método que ignora el estado real de deterioro de cada lote. Nosotros somos capaces de detectar ese deterioro antes de que sea visible. Nuestro dispositivo monitorea el estado del tomate durante su recepción, identificando cambios que las personas no pueden percibir. Además, permite estimar el tiempo de vida útil del tomate mediante la medición de parámetros como concentraciones de CO2, temperatura y humedad del alimento, facilitando una mejor gestión del producto. Esto permite tomar decisiones a tiempo, evitando que productos en mal estado continúen en el proceso de venta. En base a lo narrado anteriormente, actuamos no por fecha de entrada, sino lote por lote. Esto reduce mermas, protege la calidad para el cliente y recupera márgenes que hoy los supermercados pierden sin saberlo.

Modelo de negocio

La venta de este dispositivo de monitoreo es nuestro modelo de negocio directamente a supermercados y cadenas de retail de alimentos. Se basa en un pago único por la adquisición del dispositivo y complementado con un servicio postventa de mantenimiento y actualización del modelo conforme se entrenen más datos de lotes peruanos.

Estrategia y tracción unidos:

Para atraer clientes, realizaremos pruebas piloto en supermercados que demuestren el valor del sistema en situaciones reales, lo que nos permitirá convertir a los interesados en clientes. Nuestro crecimiento se basará en expandirnos dentro de cadenas de supermercados, replicando la solución en varias sucursales. Además, mantenemos bajos costos al enfocarnos en demostraciones directas, sin necesidad de grandes inversiones en publicidad. Hasta el momento, nuestro principal avance ha sido el análisis de tecnologías existentes. Nos hemos basado en diversas patentes relacionadas con la detección de frescura y el estado del tomate, lo que nos ha permitido diseñar una solución con bases sólidas.

Equipo:

¿Por qué nosotros? Porque somos un grupo de ingenieros con un enfoque complementario. El área informática desarrolla modelos de inteligencia artificial capaces de identificar la madurez del tomate. El área industrial optimiza su aplicación dentro de la cadena de suministro para maximizar el impacto y el enfoque ambiental mide la reducción de desperdicio, emisiones y mejora en el tiempo de vida del producto. Juntos, no solo creamos tecnología, desarrollamos una solución práctica, accesible y diseñada para funcionar en la realidad del mercado.

Pedido:

Buscamos un apoyo económico para finalizar nuestro prototipo y validar su funcionamiento en condiciones reales durante el próximo trimestre. Además, estamos buscando asesoría técnica y alianzas con productores agrícolas que nos ayuden a implementar y escalar nuestra solución en el mercado peruano.

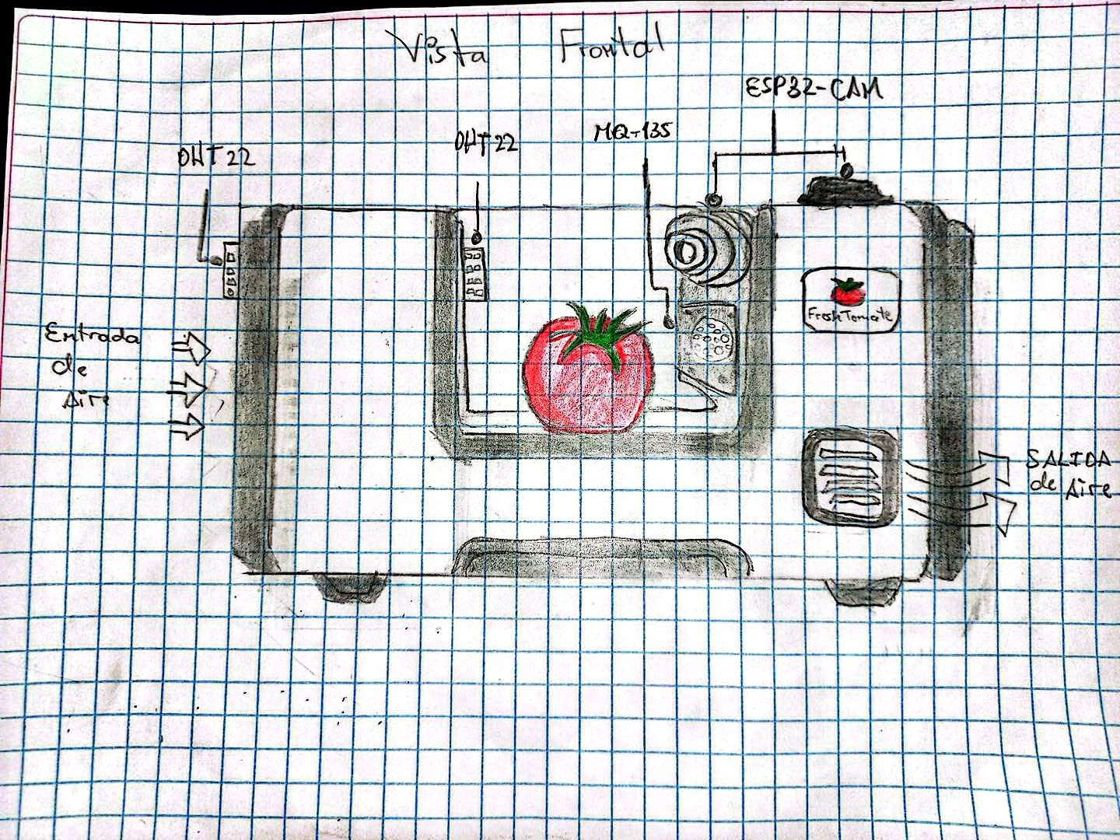
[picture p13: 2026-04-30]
FundDiseño/Talleres/taller_07/Bocetos/Boceto-3.jpeg

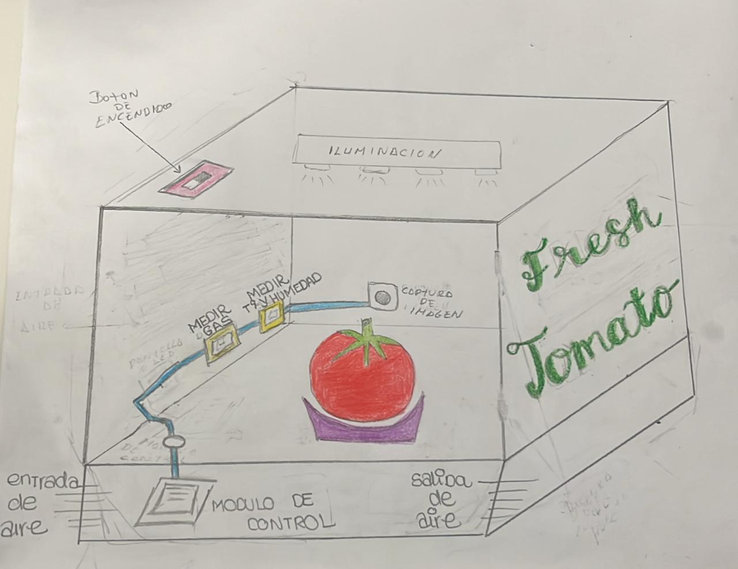
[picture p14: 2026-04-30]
FundDiseño/Talleres/taller_07/Bocetos/Boceto-2.jpeg

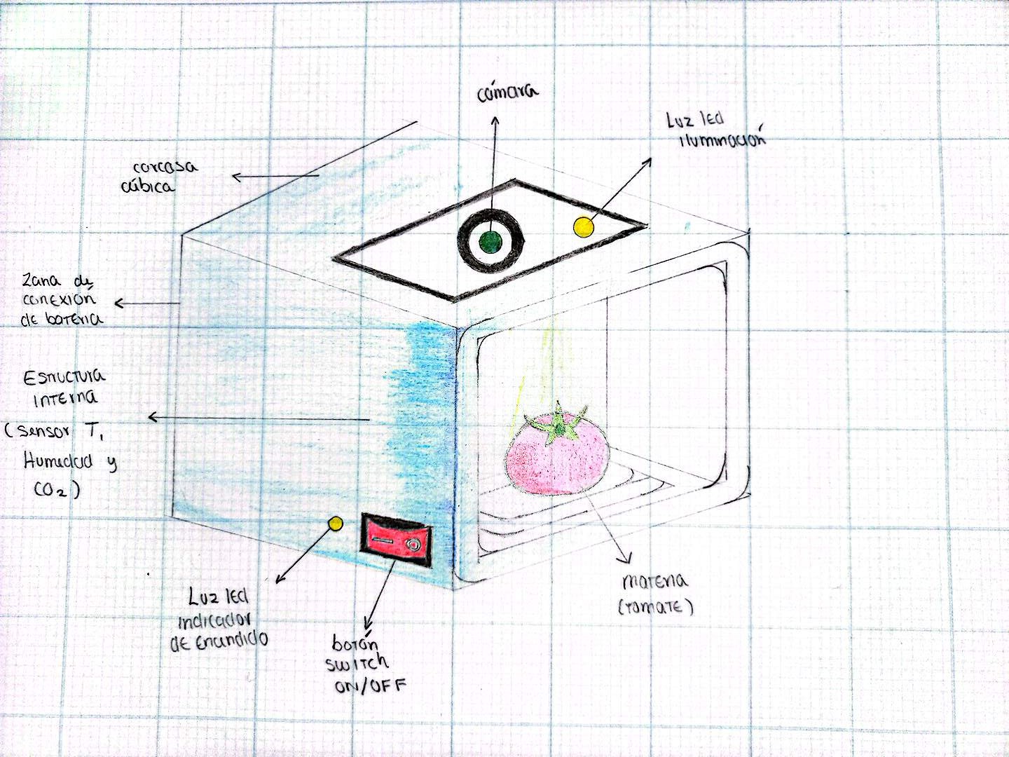
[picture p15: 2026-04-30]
FundDiseño/Talleres/taller_07/Bocetos/Boceto-1.jpeg

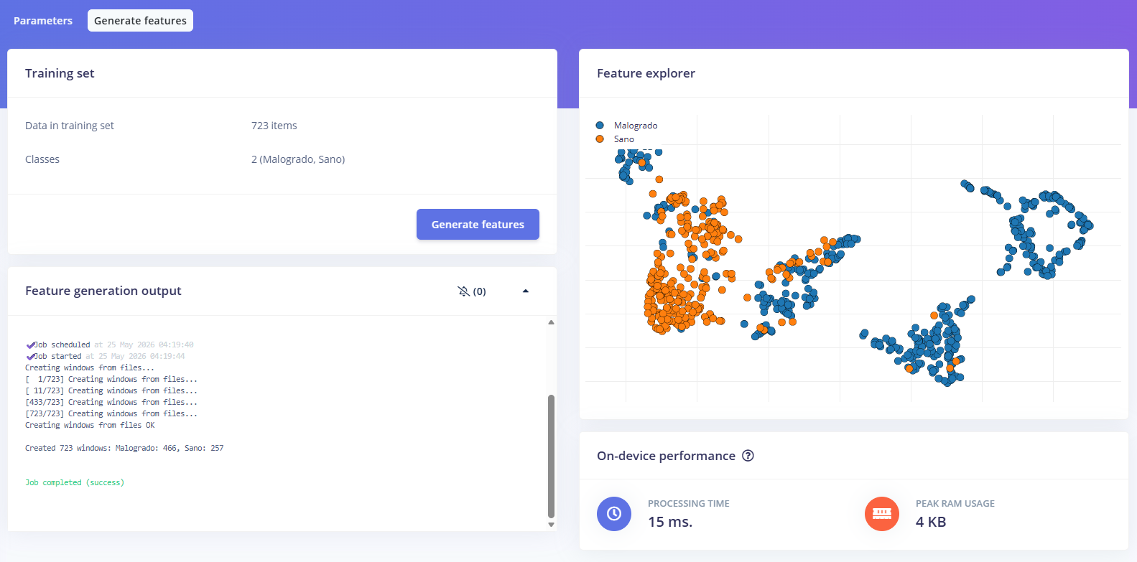
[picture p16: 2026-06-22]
Proyecto/Módulo Software/EdgeImpulse/impulse_entrenado.png

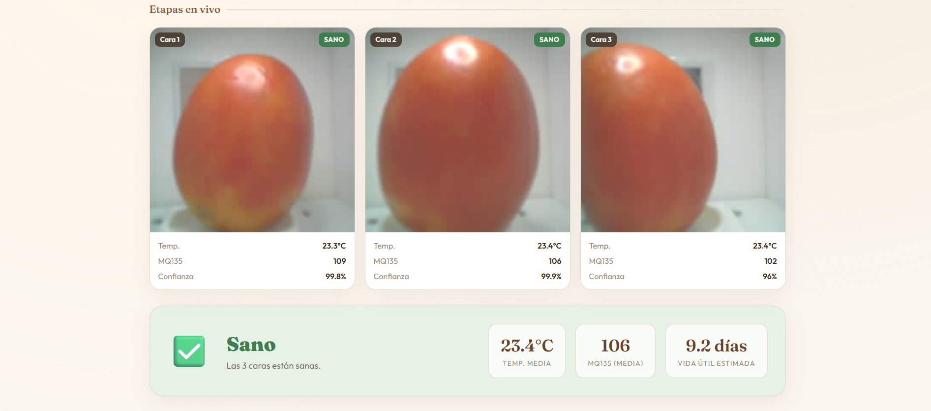
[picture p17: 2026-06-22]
Proyecto/Módulo Software/Imagenes de la Interfaz/Imagen2.png

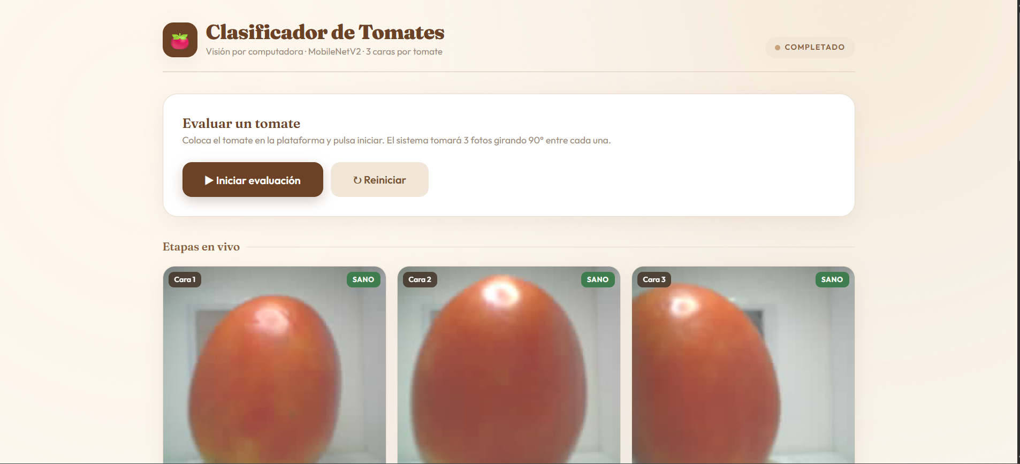
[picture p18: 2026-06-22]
Proyecto/Módulo Software/Imagenes de la Interfaz/Imagen1.png

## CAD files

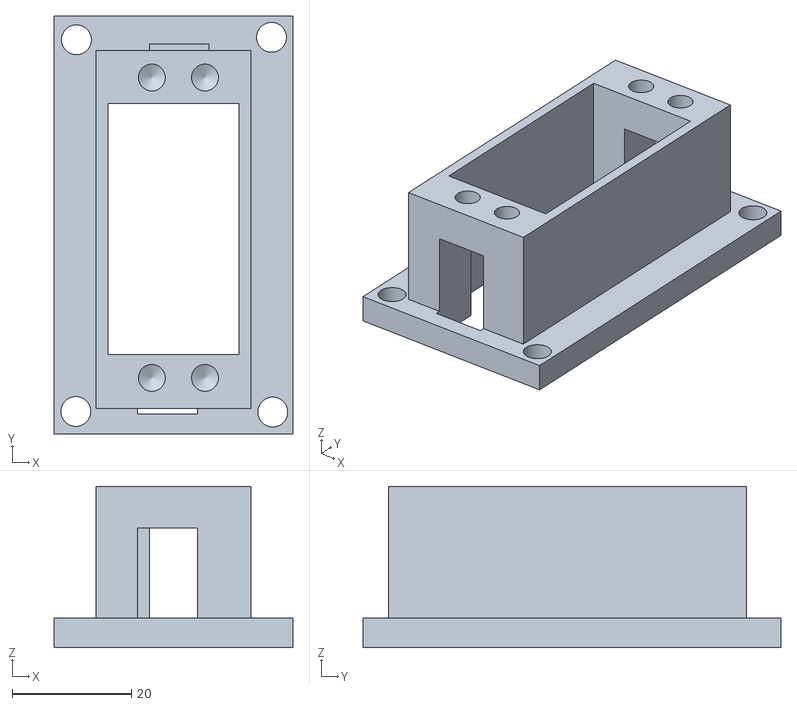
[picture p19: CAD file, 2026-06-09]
Proyecto/Módulo Mecánico/V3.0/Onshape/Partes/SOPORTE Servo V3.0.stl
40.0 x 70.0 x 27.0

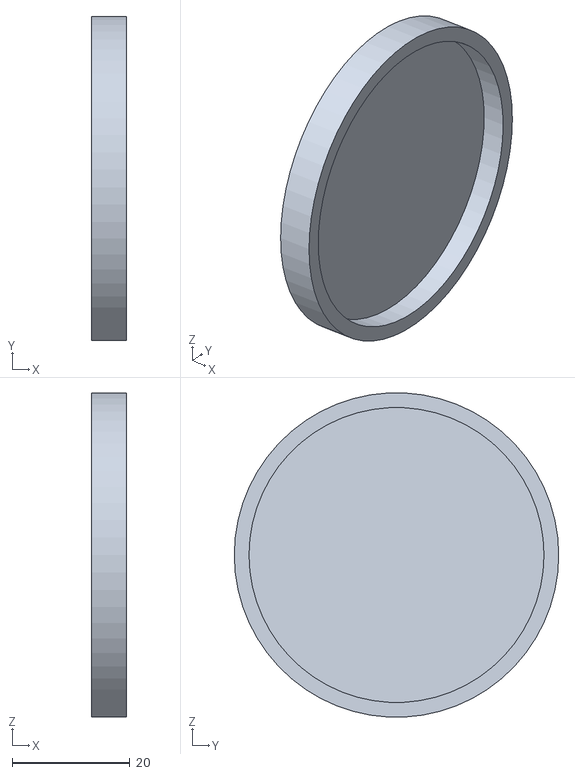
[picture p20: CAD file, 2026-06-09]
Proyecto/Módulo Mecánico/VFINAL/Onshape/Partes/Base del tomate, Unida al servomotor VFINAL.stl
6.00 x 55.0 x 54.9

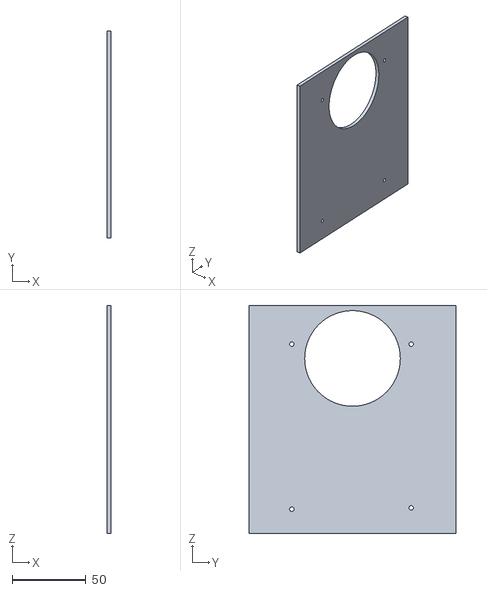
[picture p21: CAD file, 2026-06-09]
Proyecto/Módulo Mecánico/V3.0/Onshape/Partes/PLATAFORMA DE GIRO DEL TOMATE V3.0.stl
3.00 x 141.0 x 155.0

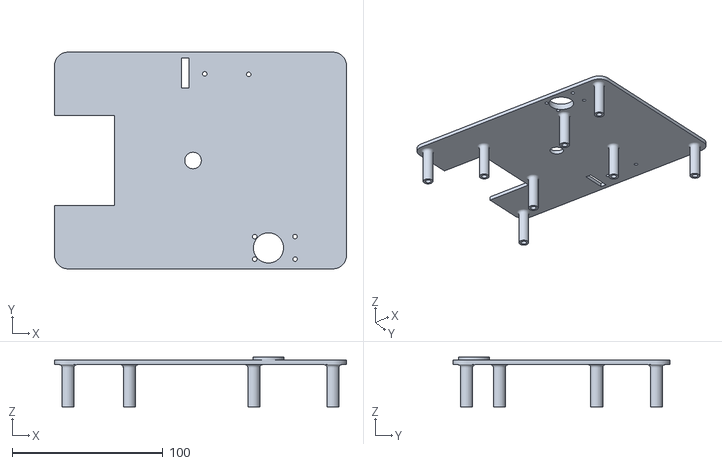
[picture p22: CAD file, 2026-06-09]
Proyecto/Módulo Mecánico/VFINAL/Onshape/Partes/Base de los sensores VFINAL.stl
194.0 x 144.0 x 33.0

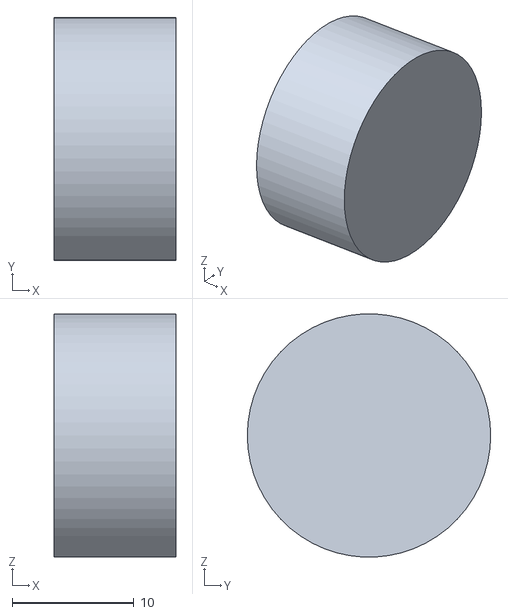
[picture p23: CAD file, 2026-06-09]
Proyecto/Módulo Mecánico/V3.0/Onshape/Partes/SOPORTE DE LA CAJA V3.0.stl
10.0 x 20.0 x 20.0

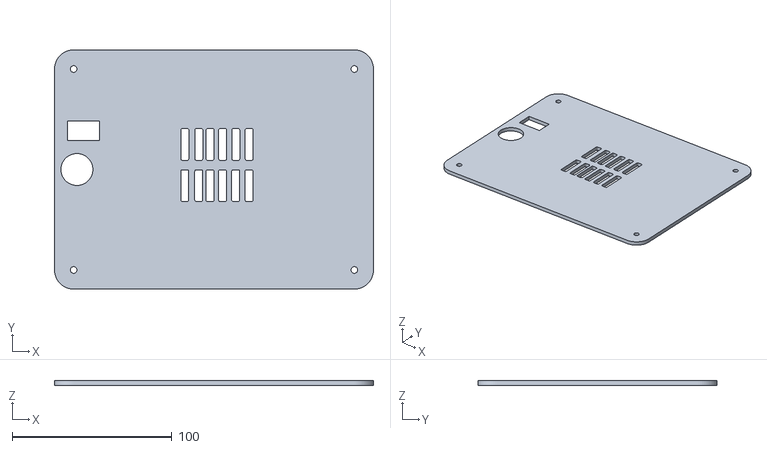
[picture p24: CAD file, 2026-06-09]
Proyecto/Módulo Mecánico/V3.0/Onshape/Partes/Tapa trasera V3.0.stl
200.0 x 150.0 x 3.00

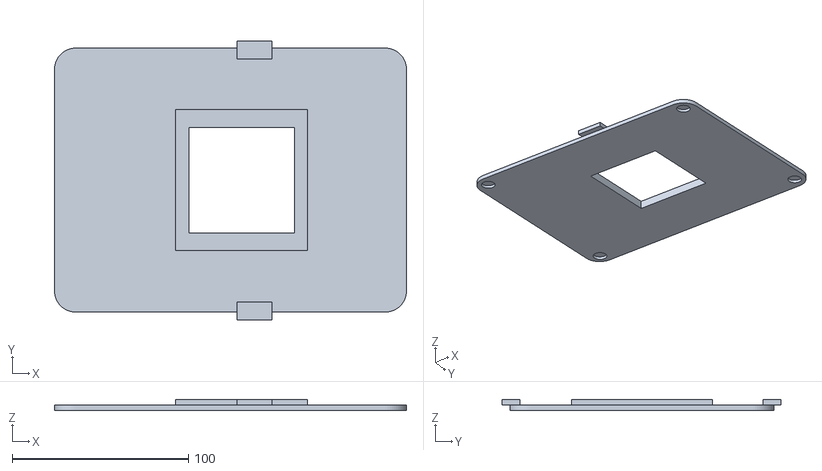
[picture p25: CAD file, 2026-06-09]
Proyecto/Módulo Mecánico/VFINAL/Onshape/Partes/Tapa delantera VFINAL.stl
200.0 x 158.3 x 6.00

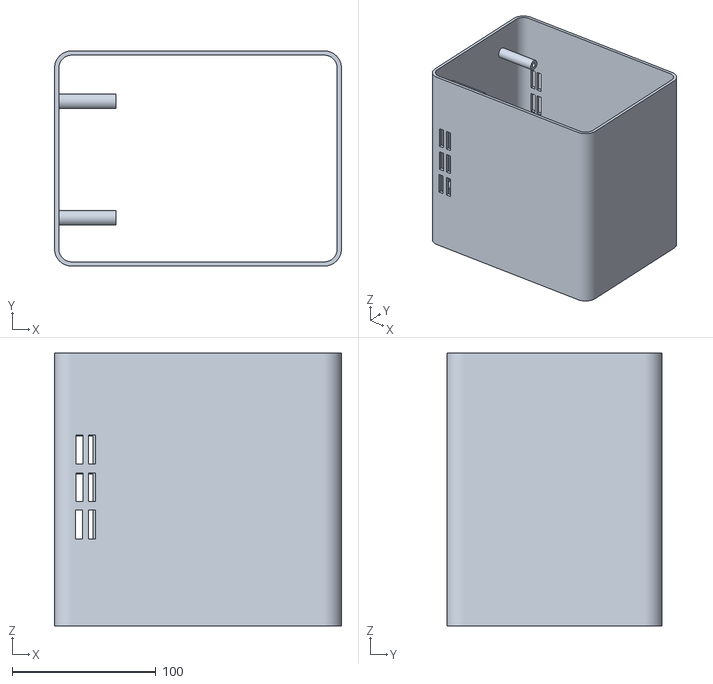
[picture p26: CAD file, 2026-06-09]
Proyecto/Módulo Mecánico/VFINAL/Onshape/Partes/CAJA DEL PROTOTIPO VFINAL.stl
200.0 x 150.0 x 190.0

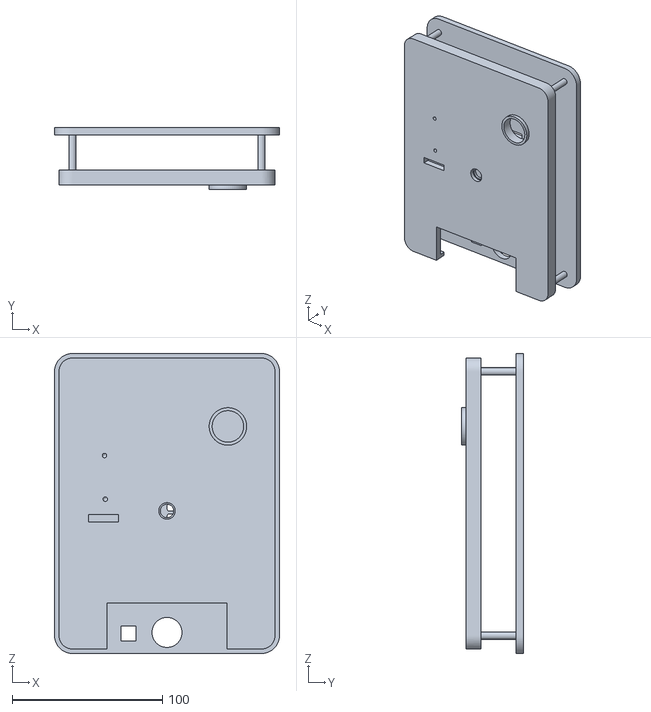
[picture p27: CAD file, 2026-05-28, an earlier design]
Proyecto/Módulo Mecánico/V2.0/Onshape/Ensamble/Modelo integrado V2.0.stl
150.0 x 41.0 x 200.0

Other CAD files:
Proyecto/Módulo Mecánico/V1.0/Onshape/Partes/CAJA V1.0.stl
Proyecto/Módulo Mecánico/V1.0/Onshape/Partes/Base de la caja tomate V1.0.stl
Proyecto/Módulo Mecánico/V1.0/Onshape/Partes/Base del tomate V1.0.stl
Proyecto/Módulo Mecánico/V1.0/Onshape/Partes/Tapa Trasera V1.0.stl
Proyecto/Módulo Mecánico/V1.0/Onshape/Partes/Tapa delantera V1.0.stl
Proyecto/Módulo Mecánico/V2.0/Onshape/Partes/Base de la caja tomate V2.0.stl
Proyecto/Módulo Mecánico/V2.0/Onshape/Partes/Base del tomate V2.0.stl
Proyecto/Módulo Mecánico/V2.0/Onshape/Partes/CAJA V2.0.stl
Proyecto/Módulo Mecánico/V2.0/Onshape/Partes/Soporte de sensores V2.0.stl
Proyecto/Módulo Mecánico/V2.0/Onshape/Partes/Tapa Trasera V2.0.stl
Proyecto/Módulo Mecánico/V2.0/Onshape/Partes/Tapa delantera V2.0.stl

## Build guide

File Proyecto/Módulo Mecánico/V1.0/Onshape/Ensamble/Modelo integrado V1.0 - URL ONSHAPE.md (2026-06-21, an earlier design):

https://cad.onshape.com/documents/3e157627b90eae232d5c05f9/w/4672de7daa23721947eefc6d/e/6da719a5ec43e0cd840542ae

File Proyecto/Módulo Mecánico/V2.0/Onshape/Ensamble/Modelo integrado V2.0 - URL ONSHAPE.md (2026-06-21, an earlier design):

https://cad.onshape.com/documents/2a6b6173812aec38a965cea3/w/13a1f8c69bccc641effa94ce/e/66f762c5a07f58269c1141a0

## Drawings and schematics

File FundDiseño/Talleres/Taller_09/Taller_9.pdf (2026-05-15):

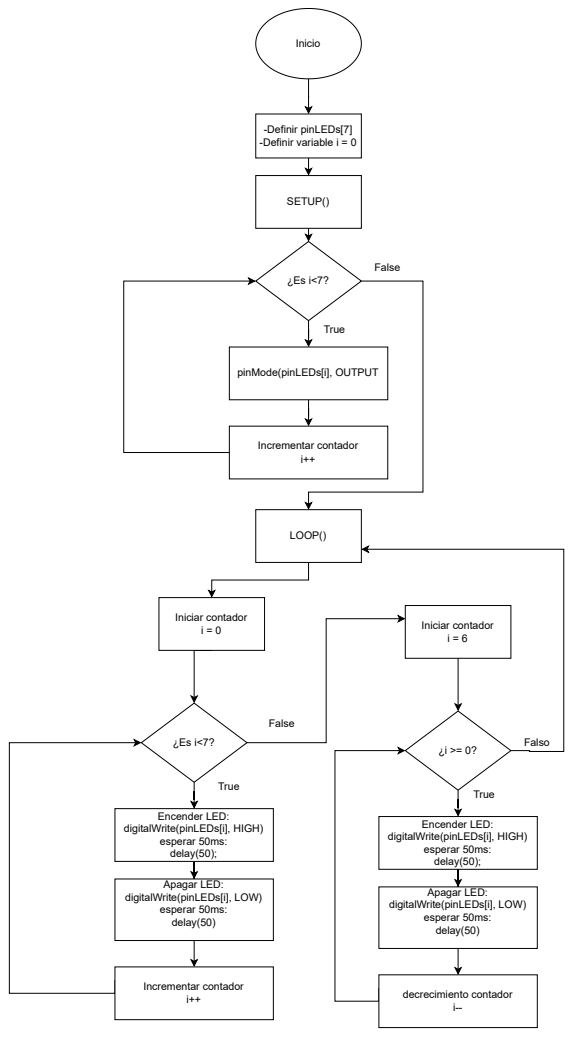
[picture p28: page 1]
-Definir pinLEDs[7] -Definir variable i = 0; Incrementar contador i++; SETUP(); LOOP(); esperar 50ms: delay(50);; Apagar LED:; False; True; Iniciar contador i = 0; decrecimiento contador i--; Iniciar contador i = 6; Inicio; Falso

pinMode(pinLEDs[i], OUTPUT

Encender LED:
digitalWrite(pinLEDs[i], HIGH)

digitalWrite(pinLEDs[i], LOW)
esperar 50ms:
delay(50)

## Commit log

2026-03-23 cambio de fotos
2026-03-24 Cambio de fuentes
2026-03-26 Guardo cambios antes de actualizar
2026-04-09 Revise introduction and propose FreshTomate system
    Expand the introduction and problem statement regarding food waste, specifically focusing on tomatoes in Peru. Introduce the FreshTomate system for monitoring tomato freshness using various sensors and AI techniques.
2026-04-23 Rename FundDiseño/Talleres/PITCH DE PROYECTO.pdf to FundDiseño/Taller_5.pdf
2026-05-21 Cambio de carpetas
2026-05-28 Taller mecanico
    [Base de la caja tomate.stl, Base del tomate (1).stl, Base del tomate.stl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]
2026-06-14 Cambios en el Proyecto
    [Base de la caja tomate.stl, Base de los sensores.stl, Base del tomate (1).stl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]
2026-06-21 Cambio en el modulo mecanico
    [Base de la caja tomate.stl, Base de los sensores.stl, Base del tomate (1).stl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]
2026-06-21 Uniendo certificados de Erick
2026-06-21 Cambio de Rose
2026-06-21 Modulo mecanico
    [Base de la caja tomate V1.0.stl, Base de la caja tomate V2.0.stl, Base de la caja tomate.stl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]
2026-06-22 Fotos de los integrantes
2026-06-22 Agregar patentes, tesis de apoyo y brochures de productos comerciales
2026-06-23 Foto de Rose
2026-06-24 Penultimos cambios de los recrusos
2026-06-24 Cambios de carpetas
